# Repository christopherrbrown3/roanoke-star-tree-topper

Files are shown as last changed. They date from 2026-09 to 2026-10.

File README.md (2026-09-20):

# Roanoke Star Tree Topper

<div align="center">






<br>

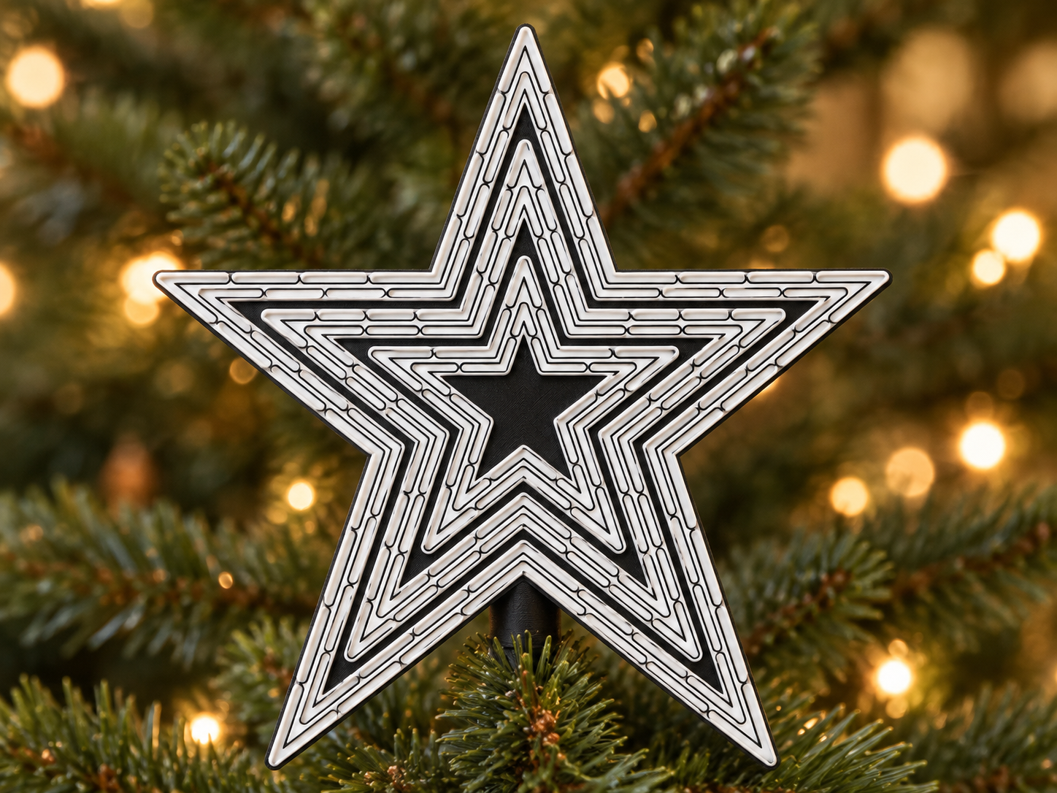
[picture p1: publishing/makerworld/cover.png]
Two-color Roanoke Star tree topper on a lit Christmas tree


<br>

**A research-informed miniature of Roanoke’s Mill Mountain Star**<br>
200 mm · two colors · one print · no assembly

</div>

The Roanoke Star is one of Virginia’s most recognizable night-time landmarks. This tree topper translates its layered neon silhouette into a carefully documented, print-in-place object: a dark structural star, three white backing bands, 130 individually outlined tube sections, and an integrated rear mount for a Christmas-tree leader.

> **Cover note:** The cover is an AI-generated product illustration based on the finished model and owner-supplied print photographs. The project renders and physical-print evidence below are the model’s actual release assets.

## A Christmas landmark since 1949

The Star’s Christmas connection is original to its story. The Roanoke Merchants Association commissioned it for the **1949 Christmas season**, and it was first illuminated on **November 23, 1949**. What began as a seasonal attraction became a permanent symbol above the city. The City of Roanoke records the Star’s height as **88.5 feet**. [City of Roanoke history](https://www.roanokeva.gov/1329/Roanoke-Star)

Roy C. Kinsey Sign Company built the sign with Roanoke Iron & Bridge Works providing the steel structure. Historical accounts credit Robert Little with the design. The full-scale Star was assembled flat on the ground at Roanoke’s airport, taken apart, transported up Mill Mountain, and erected on its tower. [1982 historical account, pp. 88–90](https://www.virginiaroom.org/digital/files/original/67/6354/JHSWV_11_02_1982.pdf) · [WDBJ interview preserved by Virginia Tech](https://scholar.lib.vt.edu/VA-news/WDBJ-7/script_archives/99/1199/112899/112899.m.htm)

The landmark is not a single outline. It is **three nested structural stars** carrying multiple neon sets. Historical descriptions give the Star an 88.5-foot height, a 100-foot supporting tower, a 6.5-foot-deep concrete base, and roughly 2,000 feet of neon tubing. The City’s public-art record and site descriptions confirm the three-star construction. [City description](https://www.roanokeva.gov/1329/Roanoke-Star) · [City art catalog](https://www.artworkarchive.com/profile/roanoke-arts/artwork/roanoke-star)

That layered construction is the heart of this design. The three white bands are the topper’s visual translation of the landmark’s nested neon faces; the dark gaps and rounded tube ends make each run read as an individual piece of neon instead of a single printed line.

## The design in one glance

| | |
|---|---|
| **Scale** | 200 mm tall · 190.96 mm wide · 50.84 mm deep |
| **Face** | Three white star bands with 130 individually outlined tube sections |
| **Construction** | Print-in-place body, face details, and integrated tree socket |
| **Material** | Two compatible PLA colors; dark structural body with white tubes and backing |
| **Target machine** | Bambu Lab A1 with AMS lite · 0.4 mm nozzle · 0.20 mm layers |
| **Assembly** | None; the star and rear mount print as one object |

## From photographs to a printable star

The geometry was developed from municipal records, historical accounts, archival finding aids, aerial views, night photographs, close-up tube studies, and more than fifteen reference views. The research deliberately separates what a photograph can show from what it cannot: an observation-deck photograph looking upward compresses vertical spacing, while an oblique view makes one side appear wider than the other. Those perspective effects are documented in the [perspective audit](research/ACCURACY_AUDIT.md).

The documented 88.5-foot height anchors the scale. Published widths disagree: the Smithsonian inventory records approximately **88.5 × 84.5 feet**, while the City’s art catalog lists **1062 × 1200 inches** without a dimensioned elevation that identifies the axes. This model uses the 84.5/88.5 proportion as its photographic reconstruction basis. Compare the [Smithsonian inventory](https://siris-artinventories.si.edu/ipac20/ipac.jsp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) with the [City art catalog](https://www.artworkarchive.com/profile/roanoke-arts/artwork/roanoke-star); the exact construction is inspectable in the [angle worksheet](research/ANGLE_WORKSHEET.md), [coordinate table](research/candidate_angles.csv), and [parallel-path correction notes](research/PARALLEL_PATH_CORRECTION.md).

The model does not claim to recover an unpublished engineering drawing or the landmark’s complete electrical tube schedule. It is a photo-informed interpretation with explicit dimensions, repeatable construction scripts, and a clear record of the sources and assumptions. The original-plan search examined the Virginia DHR National Register nomination, NPS asset records, the City’s public Engineering plan repository, Virginia Room finding aids, and restoration-report references; no original dimensioned Star elevation or shop drawing was located in the material reviewed. See the [archive search record](research/PLAN_SEARCH.md).

### The tube language

Each nested outline uses a constant inward offset, so corresponding runs remain parallel through every point and recess, including the two lower side interior angles. The [spacing review](research/SPACING_REVIEW.md) compares those offsets with the primary aerial reference. Rounded ends and deliberate dark breaks suggest separate neon lengths, while continuous bends carry the pattern around the star’s corners. A 0.6 mm dark outline keeps the white tube sections legible at FDM scale.

The three broad white backing bands leave approximately **1.6 mm of dark space** between star groups. The tubes and bands are flush inlays, 1.0 mm deep, rather than fragile raised details. White model details occupy the first five layers against the build plate; the dark body, outline, and integrated socket continue above them.

Close photographs show interruptions along straight runs and illuminated bends around corners. A high-resolution Commons photograph provided observations of breaks near the quarter points of one long run; Ben Schumin’s close-up series supplied additional night views. Those observations informed the rounded sections and dark gaps, while symmetry and repetition complete the printable pattern. The **130-section count describes this print**, rather than an inventory of the landmark’s glass tubes or electrical circuits. See the [tube-layout study](research/TUBE_LAYOUT.md), [recorded image observations](research/tube_joint_observations.json), [Schumin close-up series](https://www.schuminweb.com/photography/roanoke-star-night/), and [Commons photograph](https://commons.wikimedia.org/wiki/File:Mill_Mountain_Star_Neon_Lights.JPG).

<div align="center">
<table>
<tr>
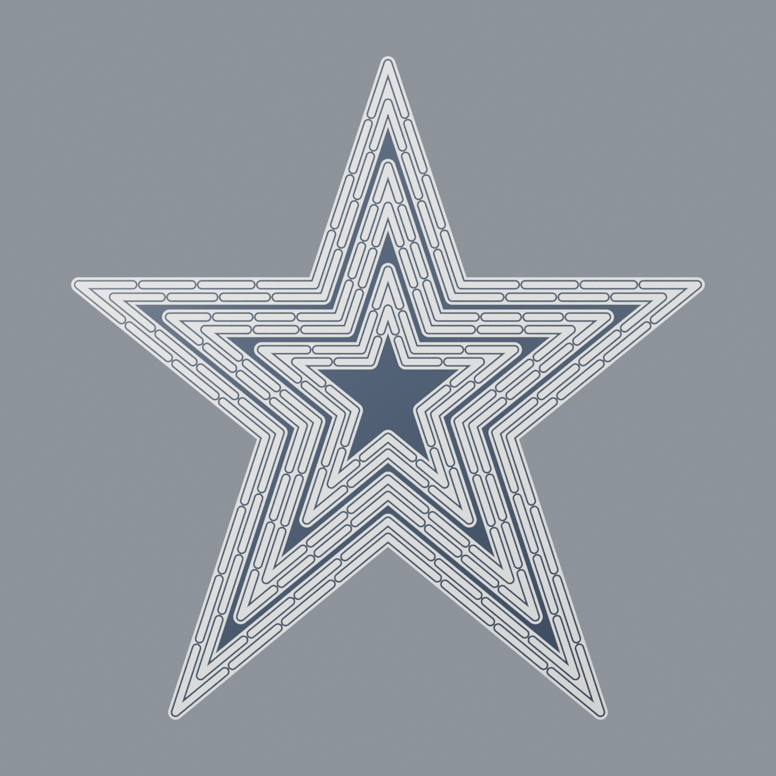
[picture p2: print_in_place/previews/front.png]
Front render showing the three nested white star bands
<td></td>
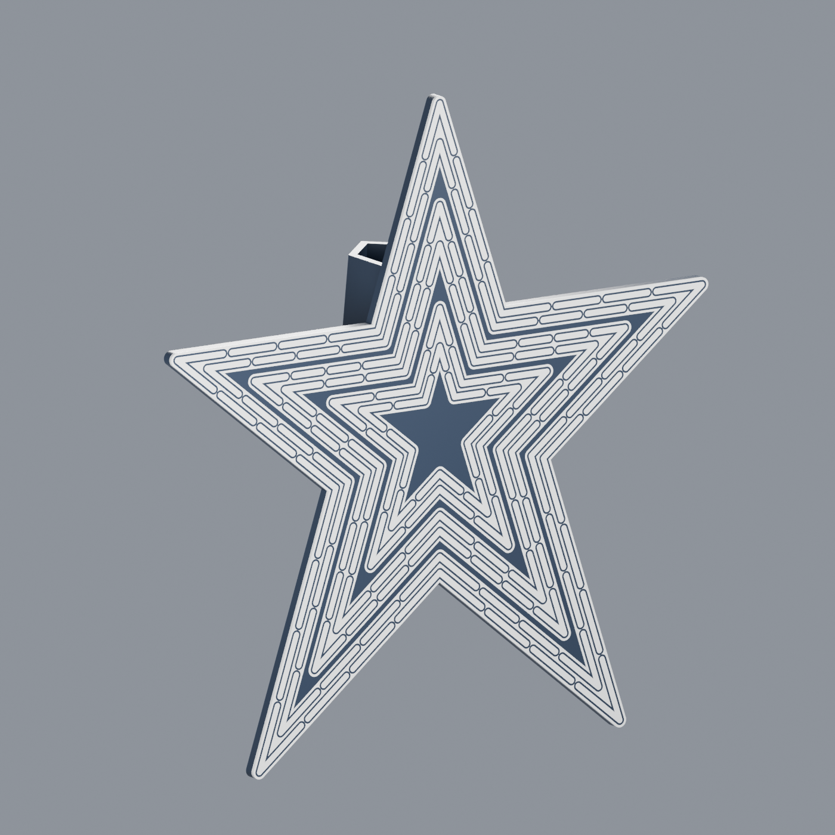
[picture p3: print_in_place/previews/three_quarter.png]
Three-quarter render showing the integrated rear mount
<td></td>
</tr>
<tr>
<td><em>Front: the layered neon pattern</em></td>
<td><em>Three-quarter: one-piece construction</em></td>
</tr>
<tr>
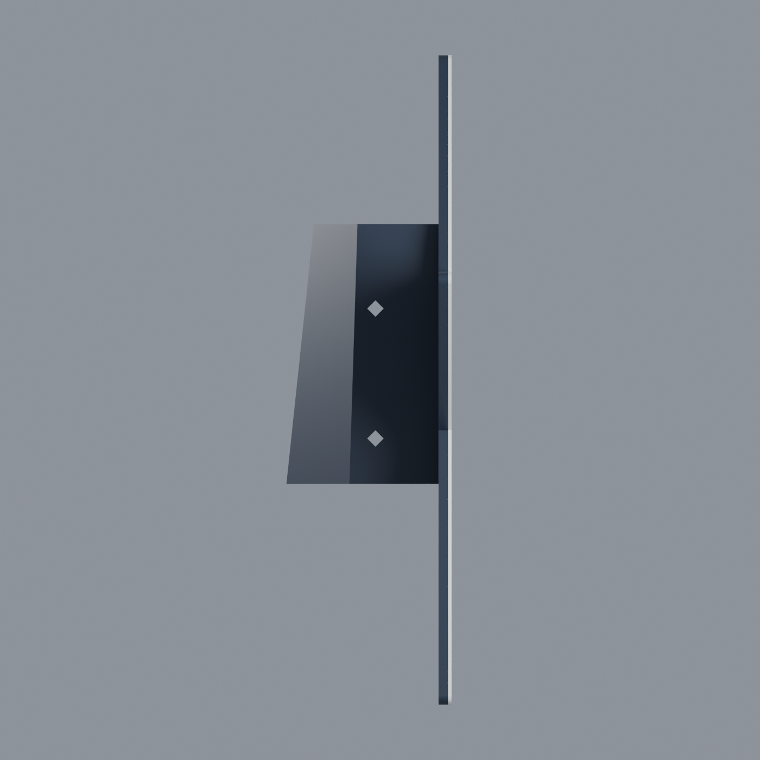
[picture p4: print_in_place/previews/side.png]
Side render showing the topper depth
<td></td>
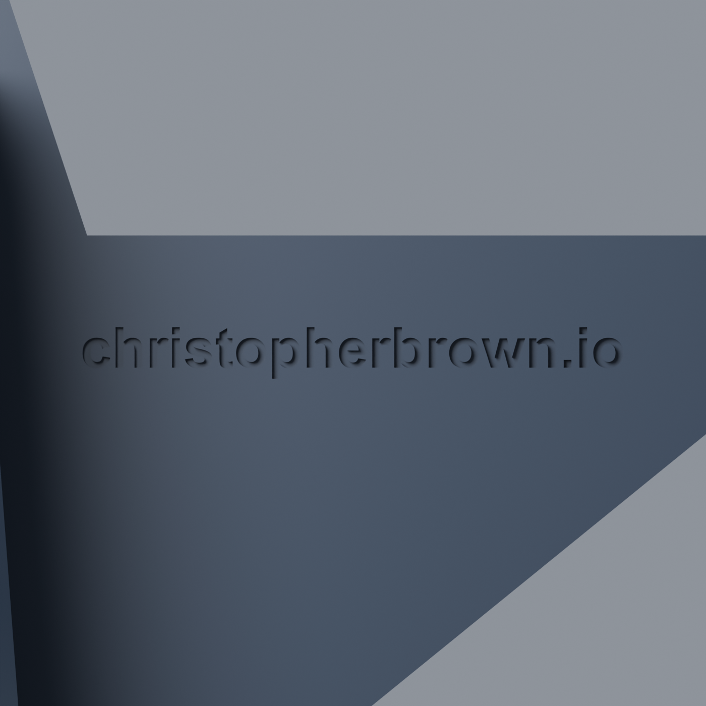
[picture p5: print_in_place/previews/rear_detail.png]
Rear detail render showing recessed christopherbrown.io lettering
<td></td>
</tr>
<tr>
<td><em>Side: shallow face, deep socket</em></td>
<td><em>Rear: recessed attribution</em></td>
</tr>
</table>
</div>

## Download the model

The design is published on MakerWorld with a dedicated A1 profile:

**[Open the MakerWorld model](https://makerworld.com/en/models/3336030-roanoke-star-christmas-tree-topper-2-color)** · **[Open the A1 two-color profile](https://makerworld.com/en/models/3336030-roanoke-star-christmas-tree-topper-2-color#profileId-3789238)**

| File | Use |
|---|---|
| **[Two-color 3MF](print_in_place/roanoke_star_A1.3mf)** | The recommended Bambu Studio project, with two filaments and explicit part assignments. |
| [Editable Blender source](print_in_place/roanoke_star_A1.blend) | Final material meshes, hidden reference paths, and embedded research, license, and validation reports. |
| [Dark body STL](print_in_place/body_material.stl) + [white face STL](print_in_place/white_tube_material.stl) | Alternative material meshes with a shared origin; import together as parts of one object. |
| [Design report](print_in_place/DESIGN_REPORT.md) | Dimensions, mount geometry, material layout, and validation results. |

The finalized [MakerWorld listing copy](publishing/makerworld/LISTING.md) and its [cover illustration](publishing/makerworld/cover.png) are included with the release assets. Personal print photographs used on the listing are intentionally not redistributed here.

## Printing, kept practical

Open the 3MF **as a project** in Bambu Studio. Filament 1 is the dark body and filament 2 is the white face detail; map those project filaments to the appropriate AMS lite spools. Keep the decorated face flat against the build plate and use the included A1 0.4 mm nozzle profile at 0.20 mm layer height.

The project uses four walls, five top and bottom layers, 15% gyroid infill, Arachne walls, and a prime tower, with supports disabled. View layers 1–5 in the slicer to see the two-color face; the full-height view looks mostly dark because the decorated face is against the bed. Select your actual build plate; the included setting is Textured PEI.

The integrated socket is 80 mm long, with nominal circular clearance tapering from **Ø34 to Ø22 mm**. Measure your tree leader before printing. The rear diamond holes accept optional retaining ties when a tree needs extra support.

The validated slice estimates **2 h 47 min and 70.5 g of PLA**, including purge and prime-tower material: 58.6 g dark and 11.9 g white. Your filament profiles and printer settings can change those estimates. The [slicer report](print_in_place/slicer_validation.json) records the exact package checked and the settings read from its exported toolpath.

The owner supplied four photographs of a successful physical print of the revised two-color face. They show the dark body, three white backing bands, and individual white tube sections. The exact slicer profile used for those photographs and post-print mechanical tests were not recorded, so socket fit, strength, and tree retention remain unverified. See the [release status](print_in_place/RELEASE_STATUS.json) for the scope of that evidence.

## Geometry and release validation

The release is checked as a model package, not only as a render:

- Watertight material meshes with consistent winding and no duplicate or zero-area triangles.
- One connected dark body and 133 white solids—130 tube sections and three backing bands—that together form a single connected print.
- Zero non-adjacent triangle-intersection candidates in either material mesh.
- Material coverage matching the complete outer solid within export precision.
- Clearance for the nominal tapered socket mandrel and geometry within the chosen 45° overhang limit.
- Recessed lettering verified for floor, depth, and clearance from the socket.
- A standard 3MF geometry round trip, two filament definitions, and explicit part-to-filament assignments.
- Native Bambu slicing with both colors, preserved process settings, and white extrusion confined to Z = 0.2–1.0 mm.
- Byte-for-byte agreement between the Blender material meshes’ STL exports and the downloadable material STLs.

See the [mesh report](print_in_place/mesh_validation.json), [intersection results](print_in_place/self_intersections.json), [scene/export check](print_in_place/scene_export_validation.json), and [rebuild guide](scripts/REBUILD.md).

## Explore the repository

| Directory | Contents |
|---|---|
| [`print_in_place/`](print_in_place/) | A1 model, material meshes, Blender scene, previews, and validation reports |
| [`scripts/`](scripts/) | Reproducible geometry construction, packaging, and checks |
| [`research/`](research/) | Sources, photograph analysis, angle measurements, and archival research |
| [`publishing/makerworld/`](publishing/makerworld/) | Published listing copy and cover-art provenance |

`main` contains the integrated single-print design shown above. Superseded models and development drafts remain available in Git history.

## Credits and license

Project by [christopherrbrown3](https://github.com/christopherrbrown3). Historical and visual references include the City of Roanoke, Virginia DHR, Roanoke Public Libraries’ Virginia Room, the Smithsonian inventory, Virginia Tech’s WDBJ archive, Ben Schumin, and Wikimedia Commons contributors. See the [source credits](research/SOURCES.md), [photograph inventory](research/GEOMETRY_REVIEW.md), and [supplied-reference provenance](research/user_provided/PROVENANCE.json).

The original model design, geometry data, and downloadable Blender, STL, and 3MF files are licensed under **[Creative Commons Attribution–NonCommercial–ShareAlike 4.0 International](https://creativecommons.org/licenses/by-nc-sa/4.0/)**. You may share and adapt the model for noncommercial purposes with attribution; adaptations must use the same license. See [LICENSE](LICENSE) for the complete terms.

Suggested attribution: **Roanoke Star Tree Topper by [christopherrbrown3](https://github.com/christopherrbrown3) · [christopherbrown.io](https://christopherbrown.io) · CC BY-NC-SA 4.0**. Identify changes when sharing an adaptation.

This license does not relicense third-party reference materials or the historical landmark itself. The back of the model carries recessed `christopherbrown.io` lettering.

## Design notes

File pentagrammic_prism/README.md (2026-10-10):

**Roanoke Star — hollow pentagrammic prism variant**

This is a separate, one-piece tree topper based on the existing A1 model. The original release files are preserved. The front outline, three white backing bands, dark outlines, and all 130 tube positions come from the existing construction profiles. The tube sections are now open slots leading into a hollow star-shaped prism. The old attachment socket is omitted.

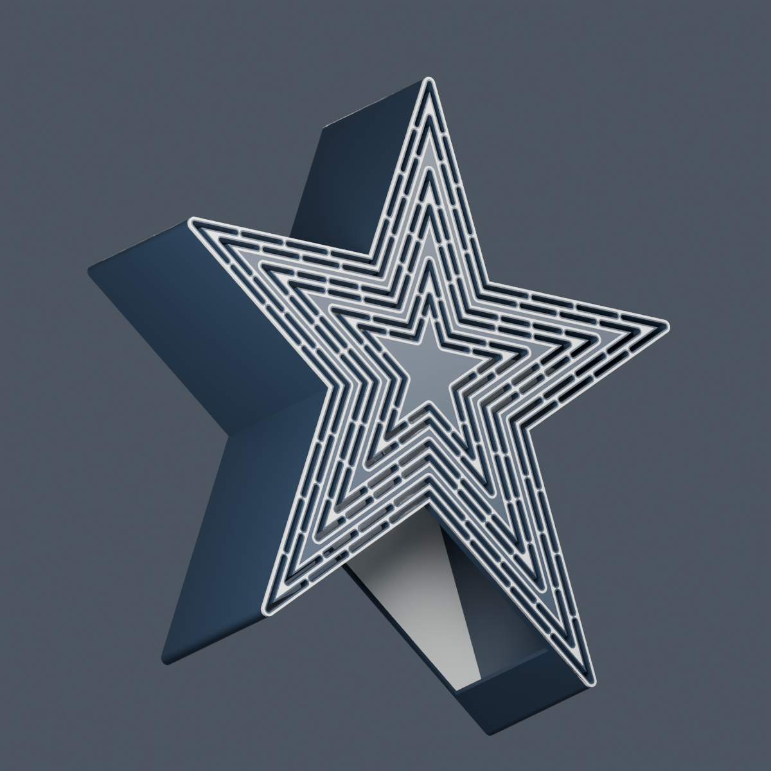
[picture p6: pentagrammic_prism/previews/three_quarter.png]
Hollow prism and lower opening


| Feature | Dimension |
|---|---:|
| Upright height × width × depth | 200 × 190.96 × 60 mm |
| Front wall | 4.0 mm |
| Side wall | 1.2 mm |
| Rear wall | 1.6 mm |
| Open tube slots | 130, nominally 1.8 mm wide |
| Lower inlet width × front-to-back clearance | 100 × 54.4 mm |
| Clear width at the star's waist | About 78 mm |
| Rear vents | Eight diamond openings, 192 mm² total |
| Solid PLA estimate, before brim, support, and purge | 126 g |

The inlet follows the lower V between the two bottom points. Its 100 mm width is intended to admit a gathered bundle of compressible branches and lights. It is not a circular 100 mm bore: the star narrows inside. A tapered 100 mm long tree-leader reference, 33.9 mm wide at its base and 13.9 mm at its tip, clears the model in the digital collision check.

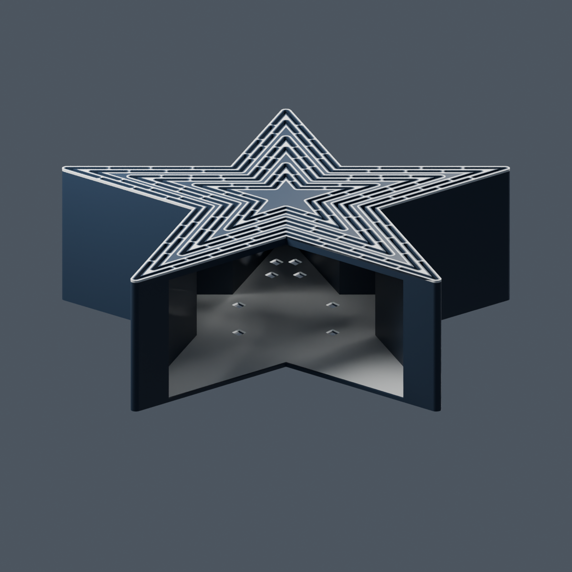
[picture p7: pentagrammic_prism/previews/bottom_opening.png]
View into the lower opening


A white inner rear surface reflects light toward the slots. The separate white mesh is a filament region in the same fused print; there is no removable back, inserted diffuser, or assembly operation. Arrange the tree's existing light string through the lower opening before seating the topper. Actual brightness and coverage depend on bulb positions and foliage.

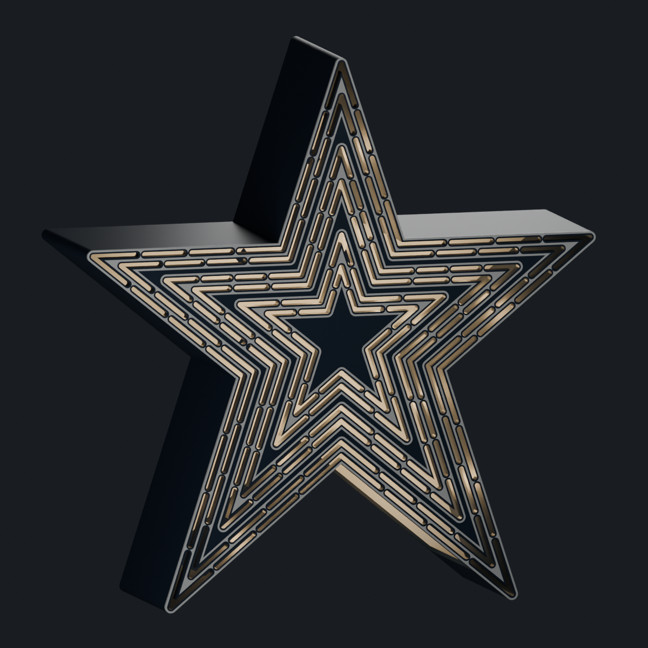
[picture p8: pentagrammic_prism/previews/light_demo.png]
Illustrative internal lighting


The lighting preview is a Blender simulation with illustrative internal lights. It is not a measurement of a real light string. Start physical evaluation with LED or fairy lights. LEDs generally produce less heat than older lighting technologies ([Australian Government lighting guidance](https://www.energy.gov.au/households/household-guides/seasonal-advice/summer?page=7)). Incandescent compatibility has **not** been heat-tested; bulb clearance and ventilation do not establish it. Tree retention, long-term strength, and real illumination uniformity also remain untested.

**Files**

- `roanoke_star_prism.blend`: editable Blender scene, built through Blender MCP. Print geometry is separated from the studio, hidden exterior reference, and optional illumination demonstration.
- `roanoke_star_prism_A1.3mf`: one multipart object with navy shell on filament 1 and white face bands/interior reflector on filament 2. Intended for the A1 and AMS lite, with a 45° print tilt, 0.4 mm nozzle, and 0.20 mm layers.
- `roanoke_star_prism_A1_single_color.3mf`: same fused geometry in one white filament, with no prime tower. Geometry and package round trip checked; its GUI slice remains pending.
- `roanoke_star_prism.stl`: complete single-piece geometry for a monochrome print. White bands lose their color distinction when printed this way.
- `dark_shell.stl` and `white_details.stl`: alternative two-material imports. Import together as parts of one object and preserve their shared origin.
- `previews/`: front, rear, three-quarter, lower-opening, and illustrative lighting views.
- `parameters.json`, `profiles.json`, and the Python sources: inspectable dimensions, geometry preparation, Blender construction, and independent validation/packaging.
- `mesh_validation.json`, `canonicalization_report.json`, and `blender_validation.json`: digital geometry evidence.

The tilted model occupies approximately 191 × 184 × 184 mm. The tilt keeps the planar faces and extruded walls within a 45° surface-overhang envelope, avoiding a large horizontal interior roof. A wide adhesion brim is included for the two lower tips, and automatic tree support is enabled from the build plate. Review the slice before printing. The slanted two-color face requires color changes through many layers and can consume substantially more purge material than the original face-down design.

The completed two-color slice in Bambu Studio 02.05.00.66 estimates **42 h 32 min and 661.49 g**, including 459.97 g of purge and 66.99 g for the tower, with 910 filament changes. The model itself is 118.95 g in the slicer estimate. No print was sent. The G-code hash, package hash, settings, and review scope are saved in `slicer_validation.json`; generated G-code stays local and is ignored by Git.

**Rebuilding**

Run `python3 pentagrammic_prism/prepare_profiles.py` from the repository root. This creates the simple source extrusions in `construction/` without modifying the original profiles or release. The preparation script requires NumPy, Trimesh, Shapely, and mapbox-earcut.

In a fresh Blender scene connected through MCP, send the contents of `build_blender.py` to `execute_blender_code`, followed by `setup()` and `build_shell()`. For the next call, resend the function definitions, call `restore()`, then `partition_colors()` and `finish()`. The code uses native imports, booleans, rendering, and saving compatible with MCP safe mode. It does not need Python file access within Blender. If changing dimensions, update the preparation configuration and pass the corresponding parameter dictionary as `C` before the build calls.

Run `canonicalize_exports.py` locally after the native exports. Return the canonical meshes to their matching Blender objects using native STL import, preserving the materials and scene properties; re-export the material meshes. Run Blender's BVH check with zero extra tolerance. The supplied final meshes have zero nonadjacent intersection candidates. Then run `python3 pentagrammic_prism/validate_and_package.py` to check the files and rebuild the 3MF. The validation script also requires Manifold3D.

The independent checks verify watertight material meshes, a single connected fused shell, preserved face footprints, 130 matching apertures, cavity and mouth clearance, material coverage, a collision-free leader reference, and 3MF round-trip geometry. They do not substitute for a physical print or thermal test. Slicer evidence, when present, is recorded separately in `slicer_validation.json`.

Original model and this adaptation: christopherrbrown3 / christopherbrown.io, **CC BY-NC-SA 4.0**. See the repository's `LICENSE`, also embedded in the 3MF.

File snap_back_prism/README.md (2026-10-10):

**Roanoke Star — snap-back prism experiment**

This is a separate two-piece experiment based on the one-piece prism checkpoint, commit `fcb757d`. The original release and the committed prism files are preserved. It retains the original 200 mm face, three white bands, and 130 light apertures. The star is 60 mm deep with the same 100 × 54.4 mm lower opening; the cavity narrows to about 78 mm at its waist.

**Use the [full two-dot revision](two_dot/README.md) for the next topper print.** Both larger connector trials worked in the user's physical test, with a slight preference for two dots. The new revision uses that connector at all six positions, with matching larger catch windows. Print its matching front and back together; the files directly in this directory retain the earlier latch for comparison.

The preferred cover also carries a larger inset **christopherbrown.io** builder mark on its outside, 72 mm wide and 1 mm deep.

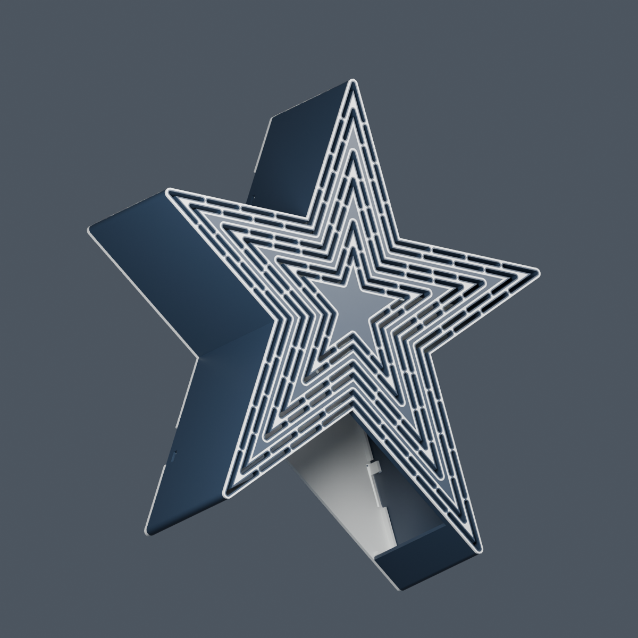
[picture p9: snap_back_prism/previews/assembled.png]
Assembled snap-back prism


The front shell prints face down with its rear open. A separate white rear cover provides the light-reflecting surface and snaps into six small windows in the side walls. A 3 mm locating rim guides it into place. Both parts slice without supports; the body has a 4 mm adhesion brim.

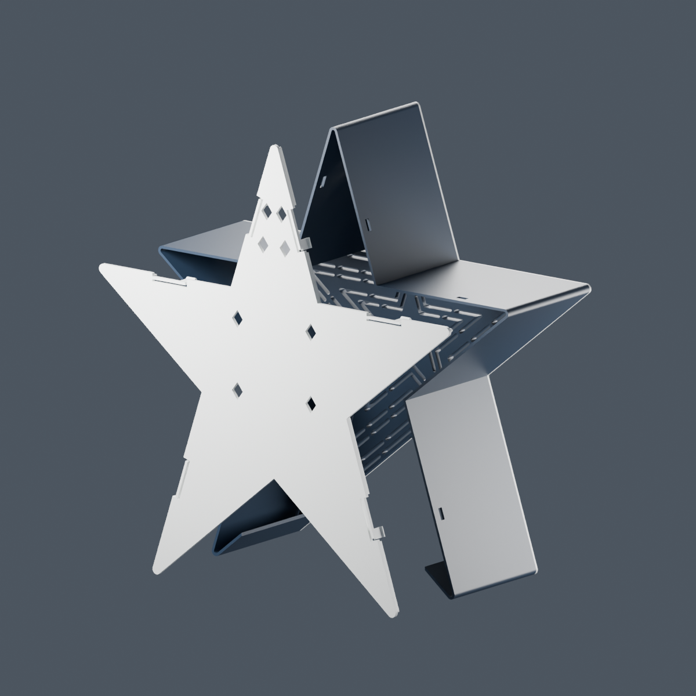
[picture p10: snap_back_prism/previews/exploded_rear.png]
Detached rear cover


Actual Bambu Studio 02.05.00.66 estimates for the A1, 0.4 mm nozzle, Generic PLA, and 0.20 mm layers:

| Print | Estimated time | Filament |
|---|---:|---:|
| Committed one-piece, two-color prism | 42 h 32 min | 661.49 g |
| Face-down front shell | 3 h 39 min | 92.72 g |
| Separate white back | 57 min | 29.09 g |
| **Snap-back topper total** | **4 h 36 min** | **121.81 g** |
| Connector sample, separate optional print | 16 min | 1.43 g |

The topper uses about **82% less filament and 89% less estimated time** than the one-piece two-color slice. The front consumes 2.35 g of purge and 0.49 g of tower material. Its six tool selections include the initial load and five color switches, all within the first 1 mm of printing. The back uses white filament only. Times include each plate's startup estimate.

**Try the small snap sample first**

The original [connector_sample_A1.3mf](connector_sample_A1.3mf) reproduces the same wall, window, spring, ramp, and locating rim as the full model. The intended behavior is that the cap seats flat with its nose in the window, stays attached, and releases without cracking. This baseline has 0.30 mm radial running clearance and 0.45 mm catch engagement. Holding force has not been measured.

The first physical sample was printed on October 3, 2026. The user reported that it stopped short of seating or required too much force, and that the small bases were difficult to remove from the plate. The [larger connector trials](connector_fit_v2/README.md) use longer spring arms, broader hooks, more guide clearance, and beveled grip edges. Both worked; the user slightly preferred the two-dot pair. The actual trial print used AMS A1's Generic PLA Silk profile, with an estimate of 32 min 49 sec and 8.85 g total. The [full two-dot revision](two_dot/README.md) applies the preferred profile to the topper. [Research and mechanism comparison](connector_fit_v2/research.md).

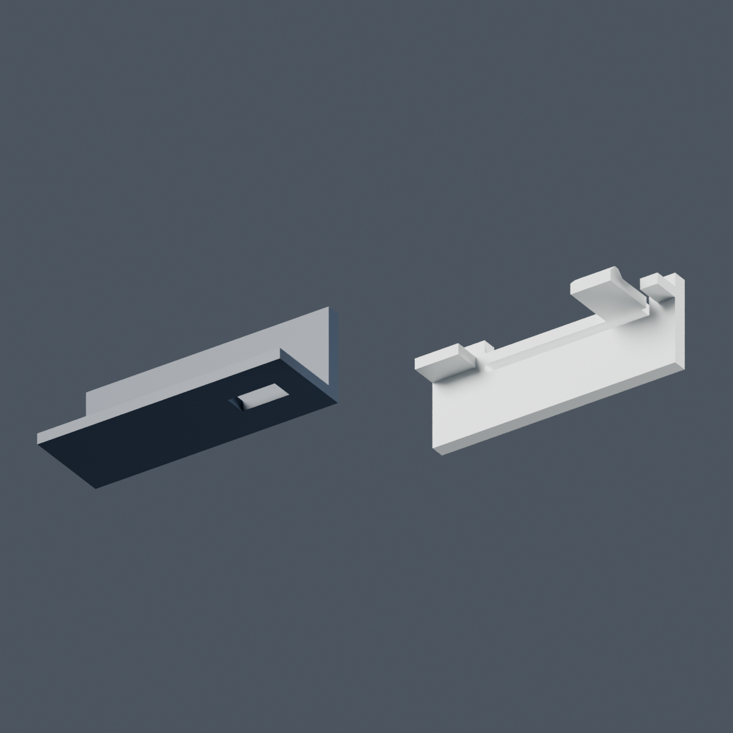
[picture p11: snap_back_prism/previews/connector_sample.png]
Connector sample


The clip's flexible arm is approximately 18 mm long and 1.2 mm wide in the plane of the back plate. Its hook projects toward the shell and uses 45° ramps. The layout follows the recommendation to orient FDM snap flexures within XY ([Formlabs snap-fit guide](https://formlabs.com/blog/designing-3d-printed-snap-fit-enclosures/)). A simple cantilever estimate gives roughly 0.42% strain for the nominal 0.75 mm insertion deflection. This estimate does not establish a fatigue life or safe holding force for a particular filament. If the sample needs adjustment, tune `radial_fit_gap_mm` or `retention_engagement_mm` in the preparation source and regenerate the actual matching profiles.

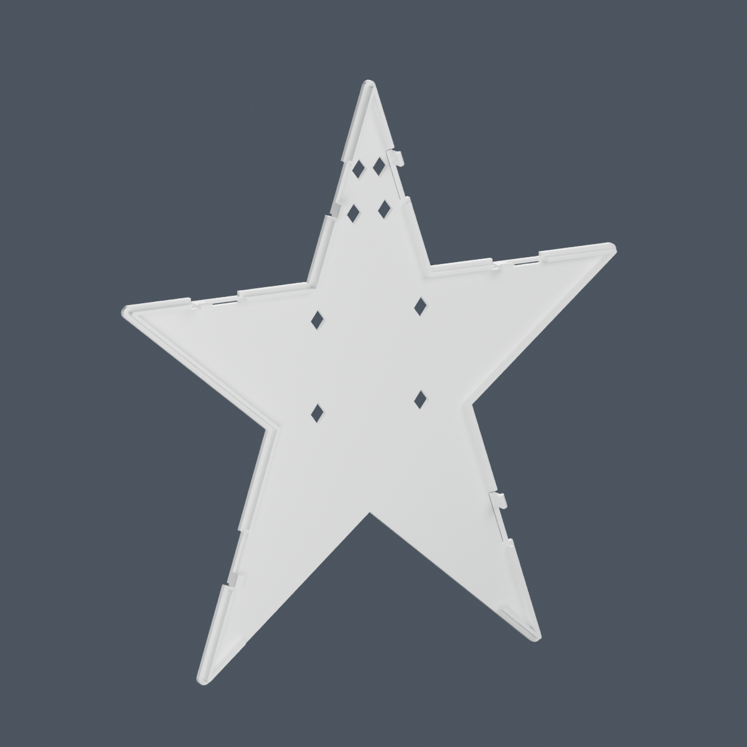
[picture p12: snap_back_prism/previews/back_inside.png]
Locating rim and six clips


**Print and design files**

- [front_shell_A1.3mf](front_shell_A1.3mf): face-down shell; navy on filament 1, original white face bands on filament 2. Preserve the supplied multipart alignment.
- [snap_back_A1.3mf](snap_back_A1.3mf): outer face down, rim and hooks up; white on filament 2. The project retains the same two-filament A1 configuration, but this plate prints only white.
- [snap_back_prism.blend](snap_back_prism.blend): editable assembled scene built through Blender MCP, with separate shell, cover, connector sample, and studio collections.
- `body_navy.stl`, `body_white_face.stl`, `snap_back.stl`: matching assembly coordinates. The shell's two material meshes form one connected print. `front_shell_fused.stl` is its single-color alternative.
- `coupon_catch.stl`, `coupon_back.stl`: sample in matching assembly coordinates; the 3MF already arranges them in their print orientations.
- `parameters.json`, `mesh_validation.json`, `blender_validation.json`, and `slicer_validation.json`: dimensions and digital verification evidence. Generated G-code is kept locally under `slicer_check/` and ignored by Git.

The geometry checks passed: watertight material meshes, one connected shell, one connected back, no seated assembly collisions, matching front footprints and 130 apertures, clear bottom opening and tree-leader reference, real catch undercuts, and 3MF round trips. Blender's BVH checks found zero nonadjacent intersection candidates. A geometric sweep also clears the hook heads after the nominal inward displacement; it does not model actual spring bending or assembly forces.

This remains an experiment pending a real snap-fit and tree-fit test. Heat and illumination have not been measured, and incandescent compatibility is unverified. Use LED or fairy lights for initial evaluation.

**Rebuilding**

Run `python3 snap_back_prism/prepare.py` from the repository root. Send `build_blender.py` through Blender MCP in a file that has the existing navy/white material definitions and no prior snap-back scene: call `setup()` and `build_body()`, then resend the definitions, call `restore()`, `build_back()`, and `finish()`. When changing the fit, supply the corresponding parameter dictionary as `C` after the definitions in each call. The code creates a new scene and saves only in this experiment's directory.

Run `python3 snap_back_prism/canonicalize.py` locally, then send the Blender definitions again and call `restore()` and `import_canonical()` to synchronize the cleaned export meshes into the scene. Run `python3 snap_back_prism/validate_and_package.py` for clearance checks and native A1 package creation. The local scripts require NumPy, Trimesh, Shapely, mapbox-earcut, and Manifold3D. Re-slice changed packages in Bambu Studio and export their G-code as `slicer_check/front.gcode`, `back.gcode`, and `sample.gcode`; `audit_slices.py` records the matching hashes and comparison.

Original model and adaptation: christopherrbrown3 / christopherbrown.io, **CC BY-NC-SA 4.0**. See the repository's `LICENSE`, also included in each 3MF.

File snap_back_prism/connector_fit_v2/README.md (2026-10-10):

The original connector print stopped short of seating or required excessive force, according to the user's physical test. These two small revised samples address insertion before changing the full topper.

**Physical result:** the user reported, “They both work. Slight edge to two dots though.” The **two-dot, 0.50 mm engagement** connector is the selected profile for the [full topper revision](../two_dot/README.md). The result applies to individual connector pairs printed using A1's Generic PLA Silk profile. See [physical_fit.json](physical_fit.json).

Both use a larger cantilever latch: a 30 mm arm with a 1.6 mm width in the bending direction and an 8 mm broad hook. The original used an approximately 18 mm arm, 1.2 mm width, and 4.6 mm hook. The new guide clearance is 0.55 mm (original: 0.30 mm), with 2 mm of relief beside the arm, a 1.6 mm entry ramp, and a wider catch window. The one-dot pair has 0.30 mm catch engagement; the two-dot pair has 0.50 mm. The original had 0.45 mm engagement.

The test bases are now 48 × 20 mm, compared with 28 × 10 mm, with rounded corners, a thickened grip at the far edge, and a 1 mm bevel underneath that edge. The bevel provides a starting point for lifting after the plate cools and is flexed. These handling features are outside the mating surfaces.

Match the dots on each wall and cap. Try one dot first, then two dots. Turn the cap over so the hook points down, align the hook with the window, and press the cap over the wall. Report whether it seats fully, holds after release, and survives removal. For comparable retries, use the same filament as the test being compared.

The matching A1 project is `connector_fit_v2_A1.3mf`, with a 0.4 mm nozzle and 0.20 mm layers, without supports or a prime tower. Digital checks do not establish physical fit or holding force. The original connector, full topper, and original release files are preserved.

Bambu Studio 02.05.00.66 initially sliced the saved project successfully: **29 min 15 sec and 8.85 g of white PLA**, including startup. There are 50 layers, with a maximum height of 10 mm. See `slicer_validation.json` for the package hash and observed results.

On October 3, 2026, the user requested printing with **AMS slot A1**. Its synced profile was **Generic PLA Silk, magenta**. All four parts were assigned to that profile and re-sliced in Bambu Studio: **32 min 49 sec and 8.85 g**. The send dialog confirmed A1, and the printer accepted the job and began heatbed preheating. Bed leveling and flow dynamics calibration were enabled; timelapse was off. The saved 3MF was not overwritten with these runtime filament changes. This test uses a different filament from the original white sample, so material may also affect the physical fit result.

The research and choice of mechanism are recorded in [research.md](research.md). These are new trial dimensions, not a copy of a downloaded model or a physically proven topper latch.

Rebuild with `python3 snap_back_prism/connector_fit_v2/prepare.py`, then execute `build_blender.py` definitions through Blender MCP and call `setup()`, `build_trial('one_dot', 1, -15)`, `build_trial('two_dot', 2, 15)`, and `finish()`. Run `validate_and_package.py` locally and slice the resulting project in Bambu Studio.

Original model and adaptation: christopherrbrown3 / christopherbrown.io, CC BY-NC-SA 4.0. See the repository's `LICENSE`.

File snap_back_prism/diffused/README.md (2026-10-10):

This variant has **three continuous white star bands**, with no black outlines around the bulbs. All **130 original bulb shapes** remain as hidden light windows behind a **0.4 mm white skin**, flush with the front face. The surrounding white is 1 mm thick, with black backing from Z = 1 mm behind it to keep the illuminated pattern distinct. At the supplied 0.20 mm layer height, each bulb window has two printed layers.

The face prints down against the plate. The white bands and thin windows now form three connected white solids instead of 133 separate pieces. The combined shell geometry, bulb positions, and outside dimensions match the preceding diffused version; this revision transfers the visible black bulb outlines to white.

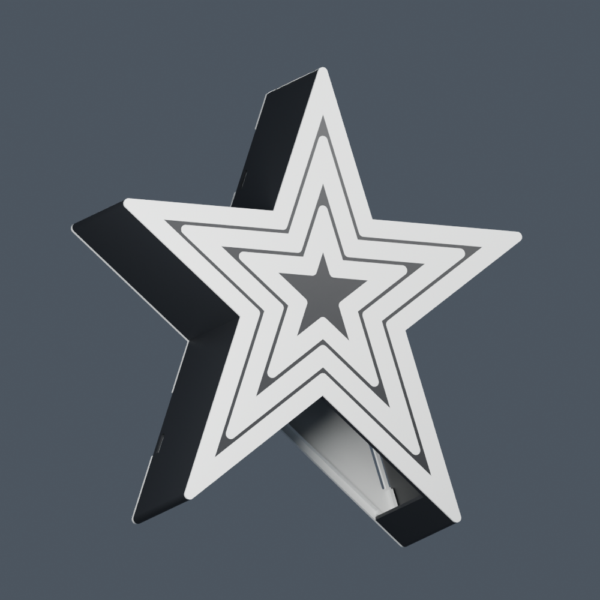
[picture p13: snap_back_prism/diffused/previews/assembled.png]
Unlit diffused star face


The 200 mm outline, 60 mm depth, 100 mm bottom entrance, and preferred two-dot connector are retained. Use the marked back from [../two_dot/snap_back_A1.3mf](../two_dot/snap_back_A1.3mf). Its inset `christopherbrown.io` mark remains 72 mm wide and 1 mm deep. The original release and earlier open-window designs are preserved.

- [diffused_front_A1.3mf](diffused_front_A1.3mf): full front shell, white on project filament 1 / AMS A1 and black on project filament 2 / AMS A2.
- [diffuser_test_A1.3mf](diffuser_test_A1.3mf): 64 × 44 × 4 mm sample at actual scale, with six complete windows and further cropped windows from the real face. A 2 mm black handling border joins the sample and provides larger edges for removal.
- [diffused_topper.blend](diffused_topper.blend): editable Blender scene containing the full topper and the test sample.
- [parameters.json](parameters.json), [mesh_validation.json](mesh_validation.json), [slicer_validation.json](slicer_validation.json), and [slice_comparison.json](slice_comparison.json): dimensions, independent geometry checks, actual test toolpaths, and native slice estimates.

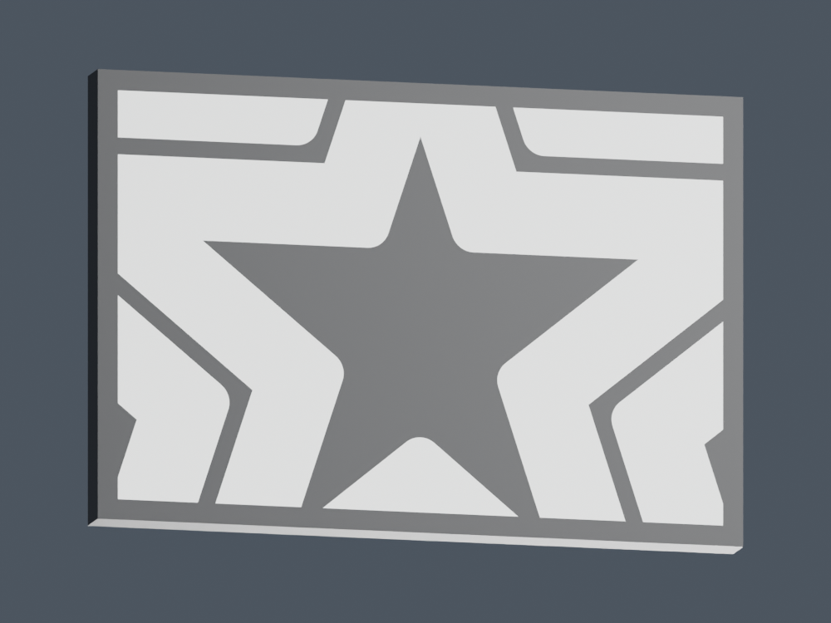
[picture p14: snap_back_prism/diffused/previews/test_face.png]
Actual-size test face


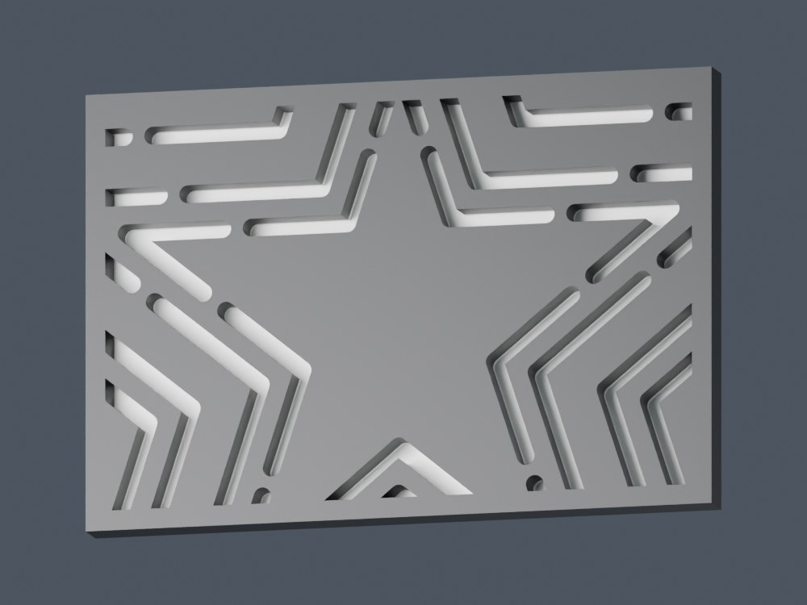
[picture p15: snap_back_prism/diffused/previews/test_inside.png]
Inside of the sample showing recessed thin windows


Bambu Studio 02.05.00.66 sliced both the full front and sample for the A1 with a 0.4 mm nozzle, Generic PLA, 0.20 mm layers, no supports or brim, and a prime tower. Exported G-code uses Textured PEI at 65 °C. Estimates include startup, purging, and the slicer's timelapse allowance:

| Project | Estimated time | Filament |
| --- | ---: | ---: |
| Previous outlined diffused front, commit `8bfcef2` | 3 h 50 min 58 sec | 95.32 g |
| Continuous white front | 3 h 55 min 24 sec | 95.01 g |
| Continuous white test sample | 51 min 37 sec | 12.90 g |

The full front uses 0.31 g less filament and takes an estimated 4 min 26 sec longer under matching settings. Removing the outlines simplifies the white geometry and appearance; the tall shell still accounts for most printing. The test has 20 layers. G-code checks verify white extrusion on layers 1 and 2 only in each of its six intact windows, no black extrusion inside those windows, and no black paths inside the continuous white star faces on the first two layers. Buffered toolpaths cover approximately 97.7% and 98.1% of the star-band interiors; this is a path-width approximation, not a measurement of the printed surface.

The **preceding outlined sample** was sent on 2026-10-04 to printer **3DP-039-922** as **Star_diffuser_test_0.4mm**, with white in physical A1 and black in A2. It continues to test the same two-layer white windows. Its print evidence is preserved in [outlined_test_print.json](outlined_test_print.json), [outlined_test_mesh_validation.json](outlined_test_mesh_validation.json), and [outlined_test_artifact_hashes.json](outlined_test_artifact_hashes.json); its model files are recoverable from commit `8bfcef2`. Completion and physical optical results are pending.

The revised sample is prepared separately and has **not been sent while the earlier sample occupies the plate**. The requested physical materials remain **white in A1 and black in A2**. A1's saved registration still reports magenta PLA Silk. A temporary sending copy uses that nominal color to let Bambu select A1, with identical geometry and Generic PLA extrusion settings. Both physical slots were verified in the send dialog, which reports the printer is busy. The revised sample is left sliced in Bambu Studio; [print_preparation.json](print_preparation.json) records that preparation. The canonical projects and previews remain white and black. Verify physical slots before sending and clear the finished print from the plate.

The membranes and complete front form one connected print. Dimensions, material boundaries, exported meshes, native slicing, and Blender triangle intersections have been checked. Actual brightness, diffusion, and unlit appearance require inspecting the physical sample with the intended lights. The assembled full topper and the force of all six clips remain to be tested.

To rebuild, run `python3 snap_back_prism/diffused/prepare.py`. Send `build_blender.py` through Blender MCP and call `setup()`, `build()`, and `finish()`. Run `validate_and_package.py`, then reimport the canonical meshes through Blender MCP with `restore()` and `import_canonical()`. The rear cover is imported directly from the preferred two-dot revision. Render the actual meshes with `preview_blender.py`, `setup_studio()`, `render_diffused()`, and `finish()`.

After slicing the sample, export the plate sliced file in Bambu Studio and run `python3 snap_back_prism/diffused/audit_sliced_test.py /absolute/path/to/sample.gcode.3mf`. This checks the material and layer count from actual extrusion instructions. Re-slice every changed project before printing.

Original model and adaptation: christopherrbrown3 / christopherbrown.io, CC BY-NC-SA 4.0. See the repository's `LICENSE`.

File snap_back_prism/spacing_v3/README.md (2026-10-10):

# Thinner star frames, spacing draft v3

This draft reduces the white band widths and widens the visible black gaps after comparison with the supplied daylight aerial photograph. The three white bands now have similar widths. A narrow black border, approximately 1.2 mm wide along straight edges, surrounds the outside star.

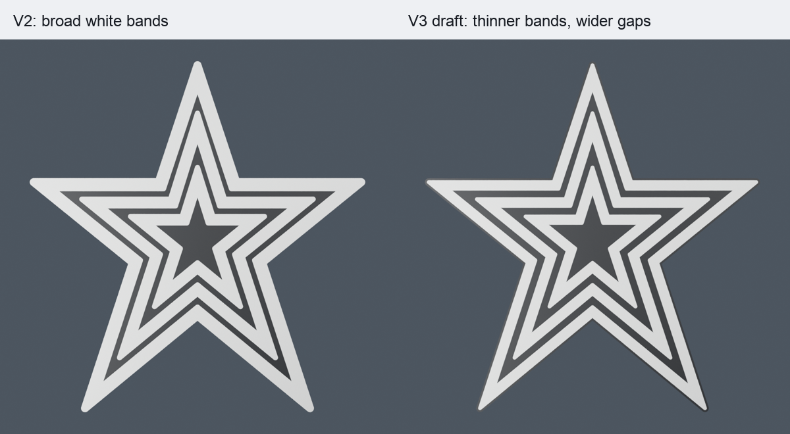
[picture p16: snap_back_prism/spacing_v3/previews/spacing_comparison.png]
V2 and the new spacing draft


| Measurement | V2 | V3 draft |
| --- | ---: | ---: |
| Outer white band at shoulder | 7.34 mm | 5.74 mm |
| Middle white band at shoulder | 6.59 mm | 5.79 mm |
| Inner white band at shoulder | 6.46 mm | 5.66 mm |
| Outer-to-middle clear gap at shoulder | 3.19 mm | 3.99 mm |
| Middle-to-inner clear gap at shoulder | 3.27 mm | 4.07 mm |
| Closest outer-to-middle gap anywhere | 2.06 mm | 2.86 mm |
| Closest middle-to-inner gap anywhere | 2.64 mm | 3.44 mm |

The photograph suggests roughly 9–10 pixels of frame width and 8 pixels of open gap at the measured horizontal shoulder. These are approximate readings from a perspective photograph, recorded in `photographic_band_measurements.json`; they are not surveyed dimensions. The model's gaps vary around the star because the established nested paths are retained. This draft changes the white backing margin around those paths, rather than changing their proportions again.

All six light-track paths and all 130 hidden window polygons are identical to V2. The windows retain their 0.4 mm white diffuser floors, and the unlit face has three continuous white stars without individual black bulb outlines. The fused shell geometry, 100 mm tree entrance, six catches, and marked two-dot back are also retained. The back STL and its print project are byte-identical to the previous back; its inset `christopherbrown.io` mark is 72 mm wide and 1 mm deep.

## Files to use

- `front_shell_A1.3mf`: two-material front shell, positioned face down; project filament 1 is white for A1, and filament 2 is black for A2.
- `roanoke_star_spacing_v3.blend`: editable Blender scene with the new front, matching back, and render lighting.
- `snap_back_A1.3mf`: matching all-white back. The previously printed marked two-dot back remains compatible.
- `body_black.stl` and `body_white_diffused.stl`: separate material meshes in their assembled coordinates.
- `front_shell_fused.stl`: the unchanged single-material geometry reference. Use the front 3MF for the intended colors.
- `previews/front.png`, `previews/assembled.png`, and `previews/spacing_comparison.png`: renders of the exported meshes.

## Verification

The black and white material meshes pass watertightness and positive-volume checks. Live Blender reports zero boundary edges, zero non-manifold edges, and zero nonadjacent triangle intersection candidates for the front materials and back. The seated back has no measured solid collision. Hash comparison confirms that all 160 protected earlier files, including V2, remain unchanged.

Native Bambu Studio slicing uses the A1 with a 0.4 mm nozzle, 0.2 mm layers, a 65 C textured PEI plate, two Generic PLA profiles, a prime tower, and no supports or brim. The front slice has 292 layers and reaches 58.4 mm. Its estimate is 3 hours 50 minutes 46 seconds and approximately 94.83 g, including flushing and the tower.

An independent audit of the first 20 layers checks the three continuous white bands and all 130 window interiors. Each window receives white on exactly layers 1 and 2, with no black extrusion in its audited interior. Buffered toolpaths with rounded bead ends approximate deposited coverage; the audited window cores exceed 90% coverage on each layer, 99% on layer 2, and 99.9% across both layers. This is a toolpath check, not a physical translucency or airtightness test.

See `mesh_validation.json`, `blender_validation.json`, `slicer_validation.json`, and `preservation_validation.json` for the checks and hashes. This spacing revision has been rendered and sliced; it has not been sent to the printer or physically tested.

## Regeneration

From the repository root, run `python3 snap_back_prism/spacing_v3/build.py`. Dependencies are `numpy`, `trimesh`, `manifold3d`, `shapely`, and `mapbox_earcut`. The script reads the V2 source and geometry snapshot files included in `../proportions_v2/`, plus earlier geometry helpers, and writes only this revision directory. Its default is three thinner white bands with the narrow black outside border. The optional `--keep-white-outer-edge` flag restores the earlier white outside edge while retaining the thinner two inner bands; that alternative requires fresh renders, a native slice, and a new audit.

For Blender MCP, submit the contents of `build_blender.py` as Python code, followed by `setup()`, `validate()`, `studio()`, `render_front()`, `render_assembled()`, and `save()`. If the revision scene already exists, use `restore()` and `reload_meshes()` instead of `setup()`, and reuse the existing studio. The code runs directly in Blender's safe mode without a file-reading or `exec` wrapper.

After exporting the native Bambu slice, run `python3 snap_back_prism/spacing_v3/audit_slices.py /path/to/plate.gcode.3mf`. The slicer report applies only to the front 3MF identified by `source_front_sha256`; rebuilding geometry requires slicing and auditing the current project again.

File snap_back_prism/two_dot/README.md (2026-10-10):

This is the full topper revision using the **two-dot connector** that the user slightly preferred after both test pairs worked. The original release, one-piece prism, earlier snap-back experiment, and printed test pairs are preserved.

The front retains the same 200 mm face, original white bands, and 130 light apertures. The star remains 60 mm deep with the same 100 mm bottom opening. The back has six 30 mm cantilever arms, 1.6 mm bending width, 2 mm relief, 8 mm hooks, 0.55 mm guide clearance, and 0.50 mm engagement. The shell has matching 9.2 mm catch windows. The hook meshes are direct transforms of the tested two-dot hook.

The outside of the rear cover has an inset **christopherbrown.io** builder mark, 72 mm wide, about 6.9 mm tall, and 1.0 mm deep. It is 52% wider and 67% deeper than the original 47.5 mm / 0.6 mm mark. The lettering retains a 0.6 mm floor and clears the vents and clips. Arial Bold is converted to mesh; the font file is not distributed.

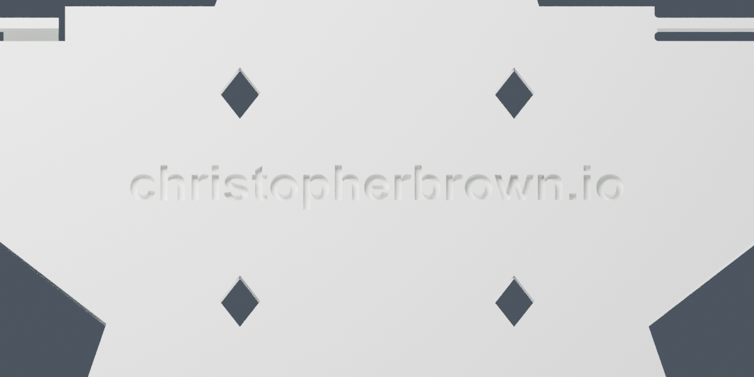
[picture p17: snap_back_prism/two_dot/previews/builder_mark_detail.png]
Recessed builder mark on the outside of the back cover


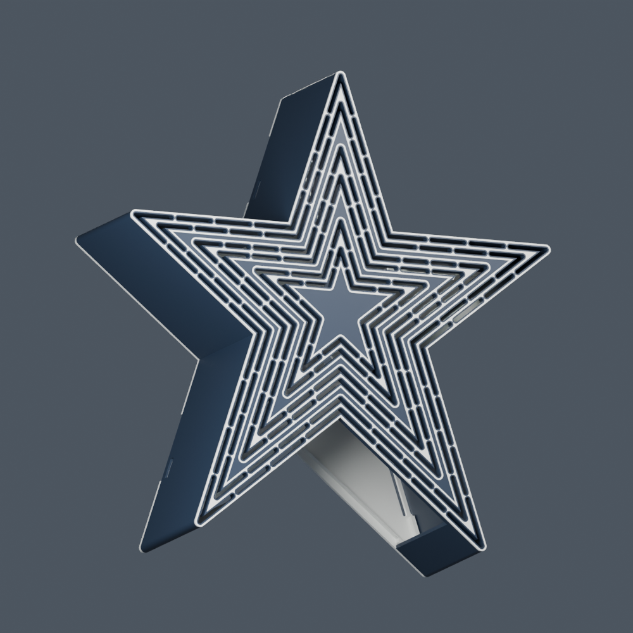
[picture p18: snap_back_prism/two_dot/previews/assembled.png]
Full two-dot topper


Bambu Studio 02.05.00.66 sliced both matching plates for the A1, 0.4 mm nozzle, Generic PLA, and 0.20 mm layers:

| Plate | Estimated time | Filament |
|---|---:|---:|
| Front shell | 3 h 39 min | 92.59 g |
| Detachable back with builder mark | 59 min 42 sec | 28.93 g |
| **Total** | **About 4 h 39 min** | **121.52 g** |

Times include startup for both plates. Neither requires supports. The front has a 4 mm brim and a purge tower for its face colors; the back has neither. The engraving appears through layer 5 at 1.0 mm, and its floor closes at layer 6 at 1.2 mm. The front package is unchanged from its previous verified slice. See [slicer_validation.json](slicer_validation.json) for package hashes and observed results. The new full topper has not been sent to the printer.

- [front_shell_A1.3mf](front_shell_A1.3mf): matching front shell, face down; navy on project filament 1 and original white bands on project filament 2.
- [snap_back_A1.3mf](snap_back_A1.3mf): matching back, outer face down with clips up; white on project filament 2.
- [two_dot_topper.blend](two_dot_topper.blend): separate editable scene built through Blender MCP.
- [parameters.json](parameters.json) and [mesh_validation.json](mesh_validation.json): dimensions, coupon comparisons, mesh integrity, assembly clearance, and package checks.
- [builder_mark_validation.json](builder_mark_validation.json): actual engraved-floor and removed-material comparisons, dimensions, and clearances.

Use both plates from this directory. The wider hooks require these matching shell windows. Map project filaments to the desired physical AMS slots before sending a full print. The successful individual test used slot A1, synced as Generic PLA Silk, magenta; the supplied full topper projects retain the original navy/white color scheme.

The individual connectors worked in the user's physical test. The assembled full topper and combined force of its six latches still need a physical check. Assembly, tree opening, and deflected-hook corridor checks are geometric checks; they do not predict force. Thermal and incandescent-light compatibility remain unverified.

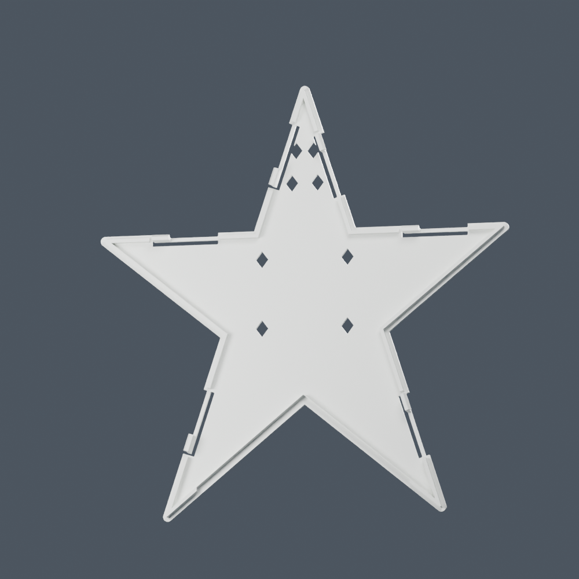
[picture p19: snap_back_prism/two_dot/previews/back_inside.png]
Back with the six preferred latches


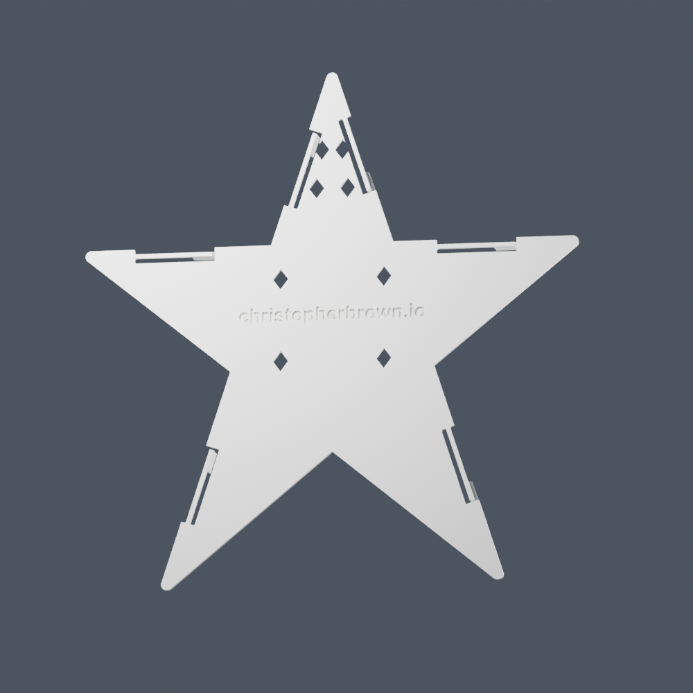
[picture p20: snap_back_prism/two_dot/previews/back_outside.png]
Outside of the marked cover


Rebuild by running `python3 snap_back_prism/two_dot/prepare.py`, then send the definitions in `build_blender.py` through Blender MCP: call `setup()` and `build_body()`, then resend the definitions, call `restore()`, `build_back()`, and `finish()`. The mark uses `/System/Library/Fonts/Supplemental/Arial Bold.ttf` on macOS; update the font path if rebuilding elsewhere. Run `validate_and_package.py`, then reimport its cleaned STLs through `restore()` and `import_canonical()`. Re-slice each changed package in Bambu Studio. To recreate previews, send `preview_blender.py` after the build definitions and `restore()`, call `setup_studio()` once, then `render_preview()` or `render_builder_mark()`.

Original model and adaptation: christopherrbrown3 / christopherbrown.io, CC BY-NC-SA 4.0. See the repository's `LICENSE`.

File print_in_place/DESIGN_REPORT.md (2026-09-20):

# Roanoke Star A1 tree topper

A single, two-color print for the Bambu Lab A1 with AMS lite: three white backing bands, 130 individually outlined tube sections, an integral tree socket, and recessed `christopherbrown.io` attribution on the back. No assembly is required.

The face and integrated mount

## Face and spacing

The star prints face-down. White tube sections and white backing bands occupy the first 1.0 mm; the surrounding dark material continues into the 4.0 mm body and rear socket. A 0.6 mm dark outline separates each white tube from its backing. Contrast defines the tubes while every front surface stays on the same plane.

All six tube paths are perpendicular offsets of the same ten edge lines. Corresponding runs remain parallel through convex tips and concave notches. The paths contain 30, 30, 30, 20, 10, and 10 tube sections. Their rounded ends and mirrored breaks interpret the photographed neon pattern; they are not a recovered historical tube schedule.

| Feature | Dimension |
|---|---:|
| Tube width / white inlay depth | 1.8 / 1.0 mm |
| Break between consecutive tube sections | 1.20 mm |
| Dark outline around each tube | 0.60 mm |
| Clear tube gaps within the three pairs | 1.937 / 1.992 / 1.865 mm |
| Clear tube gaps between paired groups | 4.195 / 4.267 mm |
| Clear gaps between the white backing bands | 1.595 / 1.667 mm |
| Body thickness | 4.0 mm |

The [spacing review](../research/SPACING_REVIEW.md) compares the geometry with the primary aerial photograph and supplied research. It supports retaining the tube positions. The backing-band width and dark outlining are choices for readability at print scale, not surveyed landmark dimensions.

## Envelope and integral socket

The complete print measures **190.960 × 199.997 × 50.836 mm** in X, Y, and Z. The front is at Z = 0, and the socket grows upward from the back. Its footprint stays behind the star's silhouette.

| Socket feature | Specification |
|---|---:|
| Axis | Star Y axis |
| Openings | Y = −32 and +48 mm |
| Length | 80 mm |
| Nominal circular clearance, lower / upper | Ø34 / Ø22 mm |
| Minimum wall | 2.4 mm |
| Bore center depth | Z = 23.4 mm |
| Roof | Two 45° facets |
| Transverse tie holes | 5 mm diamond diagonal, at Y = −18 and +22 mm |

The bore has a flat floor, vertical sides, and a pitched roof. It contains the nominal circular tapered mandrel without a horizontal ceiling. The socket overlaps the body by 0.2 mm, forming one connected dark solid. The diamond-shaped tie holes also have sloping roofs. Branch shape and fit vary; these dimensions describe available space rather than a universal tree fit.

## Recessed attribution

`christopherbrown.io` is debossed into the exposed upper-right shoulder when viewed from the back. Its 47.5 × 4.523 mm footprint is approximately 8 mm clear of both the socket and the outline. The 0.6 mm recess ends at Z = 3.4 mm, leaving 2.4 mm of material above the front inlays. Arial Bold is converted to mesh during construction; the font file is not embedded or redistributed.

Recessed attribution detail

## Two-color print project

The 3MF contains one multipart object with explicit Bambu filament assignments:

| Project filament | Geometry |
|---|---|
| 1 — dark navy or black PLA | Structural body, socket, and tube outlines |
| 2 — white PLA | 130 tube sections and three backing bands |

Both filaments feed the A1's single nozzle through AMS lite. The included configuration uses a 0.4 mm nozzle, 0.20 mm layers, four walls, five top and bottom layers, 15% gyroid infill, Arachne wall generation, supports disabled, and a prime tower. Select the actual build plate before slicing. White material is confined to the first 1.0 mm; the later body and socket print in the dark filament alone.

The earlier generic 3MF stored two display colors but omitted Bambu's part-level filament assignments. Bambu Studio imported both parts with filament 1. The exporter now records each part's `extruder` in `Metadata/model_settings.config` and includes two filament definitions. Part IDs match the referenced mesh resources, as required by [Bambu's 3MF importer](https://github.com/bambulab/BambuStudio/blob/master/src/libslic3r/Format/bbs_3mf.cpp).

Process settings also need native override metadata. Without it, Bambu Studio can replace custom values with the named system preset's defaults when opening the project. The exporter includes `different_settings_to_system`: a list of explicitly retained settings for the process, followed by entries for each filament and the printer. Its format was checked against a project saved by Bambu Studio and the official [preset-loading implementation](https://github.com/bambulab/BambuStudio/blob/master/src/libslic3r/PresetBundle.cpp). This preserves the intended walls, infill, and support settings when the system preset is resolved.

The material STLs remain an alternative: import both together as parts of one object, preserving their shared origin, then assign the two colors. The geometry-reference STL contains the complete exterior without the contrasting face pattern.

## Validation and print evidence

The [mesh report](mesh_validation.json) records independent checks against the construction profiles:

- Dark material: one watertight solid, 87,528 triangles, 77.8722 cm³.
- White material: 133 watertight solids, 77,964 triangles, 8.30384 cm³: 130 tube sections and three continuous backing bands.
- Combined exterior: one watertight solid, 9,276 triangles, 86.1760 cm³.
- Zero duplicate or zero-area triangles, and zero non-adjacent triangle-intersection candidates in both materials.
- Material overlap is negligible at numerical precision. The material union differs from the complete exterior by approximately 0.00015 mm³.
- The exported white face differs from its prepared footprint by 0.00857 mm² across 8,303.84 mm².
- The engraving-floor footprint matches the prepared lettering; minimum socket clearance is 7.947 mm.
- Zero collision with the tapered mandrel at the stated 0.05 mm radial allowance, and zero measured above-bed surface area beyond the chosen 45.05° overhang threshold.

Coplanar triangulation was canonicalized through Manifold, returned to the Blender scene, and checked without increasing intersection tolerances. The finalized Blender material meshes export byte-for-byte identical STLs to the downloadable material files. The [scene/export check](scene_export_validation.json) records both hashes and verifies that each mesh uses its intended material slot.

The 3MF is reopened programmatically to check its geometry, one-object structure, two filament definitions, part assignments, and explicit process overrides. The exact generated package was then opened and sliced in Bambu Studio 02.05.00.66 on macOS without editing the imported process or filament assignments. Each of the first five layers was visually inspected: the white bands, individual tube outlines, and separation at both lower interior corners remain visible. The sixth-layer transition to the dark body and the completed socket roof were also inspected.

An independent audit of the exported G-code confirms the A1 0.4 mm profile, 0.20 mm layers, four walls, five top and bottom layers, 15% gyroid, Arachne, Textured PEI, supports disabled, and a prime tower. Both colors occur in the model; white deposition is confined to Z = 0.2–1.0 mm, and dark material continues through Z = 50.8 mm. The 254-layer slice estimates 2 h 47 min 24 s and 70.52 g total filament, including purge and tower material. The [slicer report](slicer_validation.json) identifies the package and G-code by SHA-256; the [release status](RELEASE_STATUS.json) records the validation scope.

The owner reported a successful physical print of the earlier tube-only STL version. The white backing bands and recessed signature are subsequent changes and have not yet been physically printed. No branch-retention or load test has been performed. Digital checks do not establish those properties or verify the landmark's original dimensions.

## License and editable source

The model and geometry are licensed **[CC BY-NC-SA 4.0](../LICENSE)**, with attribution to [christopherrbrown3](https://github.com/christopherrbrown3) and [christopherbrown.io](https://christopherbrown.io). The license is included in the 3MF and model metadata. Third-party references retain their original terms.

The finalized Blender source and matching material meshes are alongside this report. Use the STL or 3MF exports for printing. The Blender file includes editable reference paths and embedded copies of the research, license, construction scripts, and validation reports. The [rebuild guide](../scripts/REBUILD.md) describes construction, export, packaging, and validation. [Research sources](../research/SOURCES.md), the [angle worksheet](../research/ANGLE_WORKSHEET.md), and the [archive search](../research/PLAN_SEARCH.md) document the evidence and its limits.

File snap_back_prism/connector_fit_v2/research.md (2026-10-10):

Research checked October 3, 2026, in response to the user's request for larger, simpler clips.

| Pattern and primary example | Evidence and practical limit | Fit for this topper |
|---|---|---|
| Protected planar spring levers — [rorys3D Robust BUCKLES](https://www.printables.com/model/281536-robust-buckles), [printed makes](https://www.printables.com/model/281536-robust-buckles/comments) | The designer describes two interlocking plates with protected compliant levers and recommends PETG. The makes include successful prints and reports of delicate arms failing under substantial tension. The page points to an updated version. | Useful evidence for broad catches, protected springs, and easy release access. A full backpack buckle would add unnecessary parts and protrusions to this back cover. |
| Simple perimeter snaps — [Extrutim Storage Box Snap-Fit Lid](https://www.printables.com/model/20961-storage-box-snap-fit-lid) | The designer supplies tight and looser lid variants, reports using PLA at 0.20 mm without supports, and notes that initial opening/closing affects fit. This is a creator report, not measured retention data. | Simple, but the star's concave perimeter makes relying on whole-wall flex less predictable than a rectangular box. |
| Rounded bead and dimple — [Dominic Böttger's printed sensor enclosure](https://dominic-boettger.com/blog/3d-printed-case-with-claude-code-openscad/) | The maker reports three PLA prints at 0.20 mm without supports, with four rounded lid bumps and matching wall dimples. | A reasonable alternative for an easy-removal cover. The tested rectangular enclosure does not establish holding force for this large star. |
| Configurable enclosure catches — [YAPP Box source](https://github.com/mrWheel/YAPP_Box), [snap parameters](https://github.com/mrWheel/YAPP_Box/blob/main/YAPP_Template_v3.scad) | Snap placement, width, and shape are parameters. Its existence alone does not establish which dimensions will work on this printer. | Supports keeping the locating fit separate from independently adjustable catches. |

[Formlabs' snap-fit guide](https://formlabs.com/blog/designing-3d-printed-snap-fit-enclosures/) recommends considering FDM layer orientation, longer compliant arms, lower engagement for easier assembly, and separate locating lugs. Its enclosure example primarily targets SLA/SLS, so its dimensions are not adopted as an FDM guarantee.

Recommendation for this topper: test a longer planar cantilever with one broad ramped hook and a simple wall window. Keep the arm within the printed layer plane and preserve face-down printing. The new tests use a 30 mm arm, an 8 mm catch, and separate guides. One and two dots identify 0.30 mm and 0.50 mm engagement. These dimensions are our engineering trial, informed by the sources, and must be judged by a new physical fit test.

Simply scaling every dimension up would also increase stiffness. The revised layout increases arm length while controlling its bending thickness and clearance. This is an inference from the cantilever geometry, not a claim that these exact samples have already been proven.

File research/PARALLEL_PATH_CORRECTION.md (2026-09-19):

# Parallel tube-path correction — 13 September 2026

The user identified visible convergence at the two lower side interior corners. A numeric audit confirmed that the independently traced paths did not have matching directions. This was a modeling defect, not merely a perspective effect in the render.

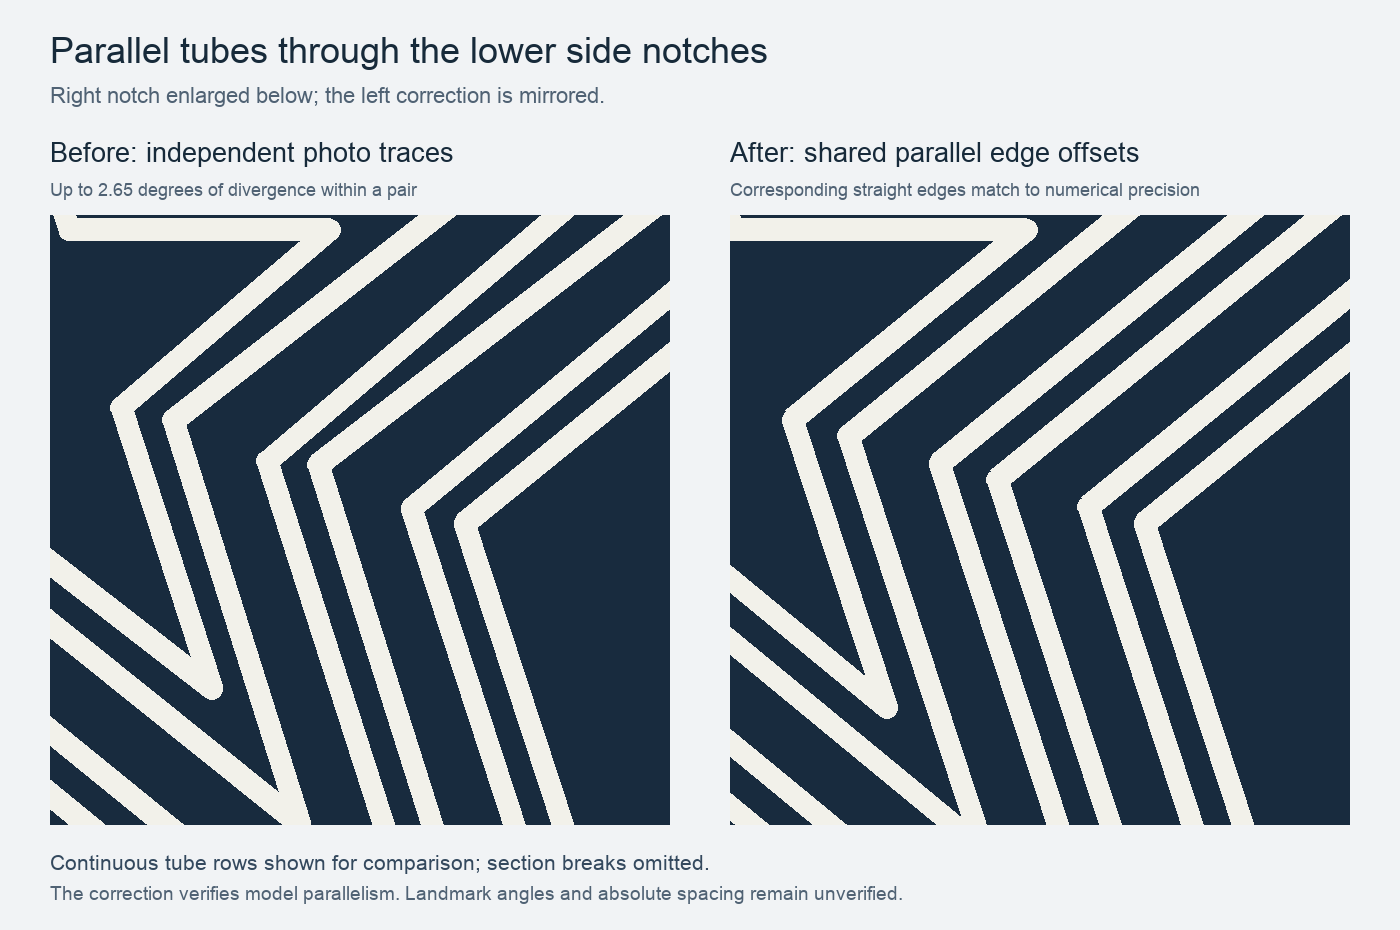
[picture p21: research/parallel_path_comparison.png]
Before and after geometry at the lower-right notch


The comparison enlarges the lower-right notch at the same scale in both panels. The left notch is its mirror. Continuous tube rows are shown to make direction and spacing visible; the printed design still has 130 individually separated tube sections.

## What was wrong

Edges are numbered clockwise from the top tip. Edge 3 runs from the right outer tip into the lower-right notch; edge 4 leaves that notch toward the lower-right tip. The matching left edges are 8 and 7.

| Pair | Prior edge-3 direction mismatch | Prior edge-4 mismatch | Prior edge-3 normal centerline gap range |
|---|---:|---:|---:|
| Paths 1 / 2 | 0.448° | 0.153° | 3.460–3.996 mm |
| Paths 3 / 4 | 2.649° | 0.246° | 2.668–4.848 mm |
| Paths 5 / 6 | 2.476° | 0.488° | 3.291–4.393 mm |

The gap ranges are endpoint projections onto the outer row's normal. They are centerline measurements, not clear edge-to-edge gaps. The two inner pairs visibly opened out along the diagonal into the notch.

## How it was corrected

All six paths now use the same ten edge directions. The outer candidate path provides the reference lines. For every nested path, those lines move inward by a single perpendicular distance; each new vertex is the intersection of its two neighboring offset lines. This keeps corresponding edges parallel and carries the constraint through both convex tips and concave notches.

Each path's offset is the least-squares fit to its previous ten vertices, measured in model millimeters. This retains a traceable relationship to the photographic reconstruction while removing its inconsistent directions. It is a design regularization, not a new measurement of the landmark. Inner vertices move by up to 4.108 mm; this is a correction to the whole nested-path construction, not just a visual adjustment to two endpoints.

| Path | Inward normal offset from outer path |
|---|---:|
| 1 | 0.000000 mm |
| 2 | 3.737158 mm |
| 3 | 9.731944 mm |
| 4 | 13.523626 mm |
| 5 | 19.590193 mm |
| 6 | 23.254967 mm |

With the 1.8 mm tube width, the straight-edge clear gaps within the three pairs are 1.937, 1.992, and 1.865 mm. The two wider gaps between pairs are 4.195 and 4.267 mm. The smallest separation between any two complete segmented white regions is 1.200 mm, at a straight-run tube interruption.

The prepared profiles have a maximum corresponding-edge direction error below 3 × 10⁻¹⁴ degrees and a normal-offset error below 2 × 10⁻¹⁴ mm. These numbers describe floating-point consistency, not achievable printer precision. Every path is a valid simple polygon and is mirrored left to right.

## Evidence and limits

The construction and measurements are reproducible with [prepare_a1_print_in_place.py](../scripts/prepare_a1_print_in_place.py). The original independently traced paths remain in [photographic_paths.json](photographic_paths.json), and the corrected coordinates and complete fit diagnostics are in [the current profile report](../print_in_place/profile_measurements.json). The [angle worksheet](ANGLE_WORKSHEET.md) and [CSV](candidate_angles.csv) now describe the corrected model paths.

Parallelism is established for the model. The absolute outline angles, frame positions, and joint schedule remain provisional because no dimensioned elevation or original tube-layout drawing has been located. The fit does not turn a photographic reconstruction into a surveyed replica.

The correction was rebuilt through Blender's GUI and exported to STL and 3MF. The owner subsequently reported a successful two-color STL print of the tube-only face. The current face retains these paths and adds white backing bands, dark tube outlines, and rear attribution. See the [spacing review](SPACING_REVIEW.md) for the follow-up assessment and the [current mesh report](../print_in_place/mesh_validation.json) for validation of the revised material regions.

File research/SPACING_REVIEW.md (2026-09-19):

# Spacing of the three paired outlines

The existing spacing is retained after review of the printed example, the source paths, and the primary aerial photograph. The three groups are already separated by clear gaps approximately twice the size of the gaps within each pair.

| Measurement, normal to a straight run | Current model |
|---|---:|
| Tube width | 1.800 mm |
| Clear gaps within pairs | 1.937 / 1.992 / 1.865 mm |
| Clear gaps between pairs | 4.195 / 4.267 mm |
| Mean centerline spacing within pairs | 3.731 mm |
| Mean centerline spacing between pairs | 6.031 mm |
| Between-pair / within-pair centerline ratio | 1.616 |

These are perpendicular distances, so a diagonal edge has the same gap as a horizontal one. Tip-to-tip distances are larger because adjacent offset lines intersect at a corner. The 1.20 mm breaks along individual tubes are a separate measurement.

## Photographic cross-check

The [City aerial image](https://www.roanokeva.gov/ImageRepository/Document?documentID=13604) remains the primary six-path tracing source. A fresh review used its original 2600 × 1461 pixel image. Two approximate vertical cross-sections through the near-horizontal shoulders locate the six illuminated centerlines at:

| Image x coordinate | Approximate image y coordinates, outside to inside | Centerline ratio |
|---|---|---:|
| 490 px | 651, 660, 675, 683, 697, 706 px | 1.67 |
| 612 px | 652, 660, 674, 683, 696, 704 px | 1.62 |

These pixel spot-checks have roughly 1–2 pixel reading uncertainty, include glow and interruptions, and are not a metric camera calibration. They corroborate the existing fit's grouping; they do not establish surveyed dimensions. Comparing adjacent lines locally reduces the effect of foreshortening, but does not remove perspective. The close [Commons neon photograph](https://commons.wikimedia.org/wiki/File:Mill_Mountain_Star_Neon_Lights.JPG) and daylight aerial views were also reviewed for the paired pattern and backing bands. Their oblique views and different lighting modes do not provide better absolute gap measurements.

The supplied research's 13 / 17 / 16 pixel within-pair intervals and 27 / 28 pixel between-pair intervals imply a **1.793 centerline ratio**, not a clear-gap ratio. Its source cross-section and camera correction are not reproducible from the supplied notes. Both estimates support wider spaces between pairs; the evidence does not justify enlarging the current geometry to one exact ratio.

## Print evidence and design choice

The owner reported a successful two-color STL print and supplied a photograph of the unengraved version. The photograph shows the paired outlines, but its perspective and lighting are unsuitable for dimensioning either the print or the landmark. It is retained privately and is not redistributed here.

At a 0.4 mm nozzle width, the clear gaps between paired tube groups are over ten nozzle widths across. The existing tube spacing is therefore retained. A wider gap can be an aesthetic preference, but would not be an established correction to the landmark geometry. The source edge directions, exact parallelism, and overall envelope remain unchanged.

## White backing bands

The subsequent face treatment adds three white bands beneath the tube pattern. Each band's outer and inner boundaries sit 2.2 mm from the corresponding tube centerlines. The resulting **clear gaps between the white bands are 1.595 and 1.667 mm**; these are different from the 4.195 and 4.267 mm distances between tube edges. A 0.6 mm dark keyline surrounds each tube so the white tube sections remain visible against the white bands. All visible regions are flush to the print bed and use the same two materials.

The 2.2 mm band margin and 0.6 mm keyline are choices for a readable, printable miniature. They are not measured dimensions of the landmark's backing panels. The actual tube positions are preserved.

See [profile_measurements.json](../print_in_place/profile_measurements.json) for the full paths and [USER_RESEARCH_REVIEW.md](USER_RESEARCH_REVIEW.md) for the distinction between photographed centerlines and clear gaps.

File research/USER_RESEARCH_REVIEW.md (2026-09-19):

# Review of supplied research and print reference — 12 September 2026

The user's two-color Christmas tree topper remains the target. The new desk-print photograph is an appearance reference. Its lighting enclosure and electrical design are outside the chosen design. The original Markdown is preserved without alteration. The photograph is represented by its source hash and provenance in [user_provided](user_provided/PROVENANCE.json); the image itself is excluded from the public repository.

## Findings to retain

- Three structural star frames are documented by the [City of Roanoke](https://www.roanokeva.gov/1329/Roanoke-Star).
- The all-white photographs support six dominant visible contours arranged in three close pairs, with larger spaces between pairs. The current candidate already models that topology. This is a visible-pattern interpretation, not a count of every physical glass tube or circuit.
- The supplied desk-print photo reinforces the dark face / white paired-outline appearance. It is oblique and cannot independently establish face-on angles, exact proportions, or spacing.
- The 88.5-foot star height has multiple historical and official sources. The supporting tower's 100-foot height is a separate dimension.
- Original drawings and recent engineering assessments remain valuable leads. They have not yet supplied verified vertex coordinates.

## Corrections and qualifications

| Supplied claim | Review | Consequence for CAD |
|---|---|---|
| The 84.5-foot width definitively proves the actual Star is not regular | The Smithsonian inventory records **approximate** dimensions. The [city art catalog](https://www.artworkarchive.com/profile/roanoke-arts/artwork/roanoke-star) gives **1062 × 1200 inches**, equivalent to 88.5 × 100 feet, without an engineering elevation or clear axis explanation. If 84.5 feet is confirmed as frontal star width, it is incompatible with an upright regular pentagram of height 88.5 feet. | Keep 84.5/88.5 as an explicit current modeling assumption; resolve the conflicting measurement sources before treating it as exact. Do not silently choose 100 feet either. |
| 0°, ±30°, ±60° edge families and a 60° apex | A photo-derived hypothesis, without the source coordinates, camera calibration, correction transform, residuals, or uncertainty needed to reproduce it. An apparent angle in a low-angle/oblique photo is not a physical angle. | Do not replace the candidate's inferred 36.66° apex with 60° on this evidence. Neither value is verified as the landmark's angle. |
| Inter-band **clear gap** is about 1.8 times paired-track spacing | The supplied pixel positions are **centerlines**. Their intervals are 13, 17, 16 pixels within pairs and 27, 28 pixels between pairs. The mean ratio is 27.5 / (46/3) = **1.79348**. | This is a ratio of cross-section centerline intervals. It is not a clear edge-to-edge gap ratio. Subtract the half-widths of adjacent lines to obtain clear gaps, and measure normal to the local edges in a metrically corrected image. |
| Frame sizes 1.00 / 0.74 / 0.43 | Useful hypotheses, but no reproducible fit data or dimensioned source accompanies them. The present candidate uses different independently traced paths. | Preserve the estimates as research; do not silently overwrite paths or force all nested contours to be scaled copies. |
| “3–5 sets” explains the electrical grouping | The city gives that wording, but the proposed interpretation of circuitry versus fabricated pieces is not established by a wiring/shop drawing. | Avoid claiming a complete historical tube or circuit layout. |

A low-angle photograph can foreshorten the vertical dimension and widen the apparent apex; yaw and roll add further distortion. A free homography can fit different underlying shapes to the same photo. Even several unconstrained homography overlays are insufficient proof of metric accuracy. See [ACCURACY_AUDIT.md](ACCURACY_AUDIT.md).

## Interior and exterior angles

[ANGLE_WORKSHEET.md](ANGLE_WORKSHEET.md) reports every vertex of the **current candidate**, with full calculations for all six paths in [candidate_angles.csv](candidate_angles.csv). Interior angle, signed exterior turn, and outside sector are separately defined. The worksheet is a transparent record of the model, not a recovered original specification.

## Design carried forward

The latest model in [print_in_place](../print_in_place/DESIGN_REPORT.md) has 130 white inlay sections along six paths in three pairs, a continuous dark backing, and an integral hidden tree socket. The user chose a single print with no assembly on a Bambu A1 with AMS lite. The white solids and dark body fuse in the same print; no removable inserts or mount fasteners are needed. The reference desk print's individual dash lengths are not treated as original neon segment dimensions. No LED enclosure, wiring, diffuser, or electronics has been added.

Both actual color meshes in the A1 model report zero non-adjacent triangle-intersection candidates, and independent checks validate the fused solid and material coverage. The owner subsequently reported a successful two-color STL print of the tube-only face. The current face adds three white backing bands and dark tube outlines, with recessed attribution on the back. The [spacing review](SPACING_REVIEW.md) documents that change and distinguishes it from the earlier physical print. Mesh validity does not establish landmark fidelity; the exact historical geometry remains unresolved.

## Provenance of the secondary print

The supplied kitchen-counter photograph has no verified model page or creator attribution in the task. The separately linked [MakerWorld model by Higgins](https://makerworld.com/en/models/380234-roanoke-star) calls itself a recreation and supplies no engineering provenance. It was not used as a dimension source or imported into the CAD. The page was publicly viewable; a failed automated fetch was not evidence of a paid model.

See [PLAN_SEARCH.md](PLAN_SEARCH.md) for archive findings and the scope of the material examined.

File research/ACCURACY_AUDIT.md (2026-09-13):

# Accuracy audit — 10 September 2026

**Finding: photographic fit does not establish exact landmark geometry.** This audit documents the constraints and limitations of the reconstruction used as the model’s starting point.

## The main methodological weakness

The city photograph was traced accurately in image space, but the inferred face-on geometry depends on assumed symmetry, level shoulders, approximate parallelism between paired tube edges, and a published overall aspect ratio. The pair-parallelism assumption has not been established by a drawing or measured landmark dimensions.

The later drone comparison fitted a free projective transform. Such a transform can absorb changes in the underlying face-on proportions. A lower reprojection error therefore supports image-space consistency, but does **not** independently prove correct apex angle, shoulder height, lower-leg length, or nested spacing.

`audit_projective_ambiguity.py` constructs three example shapes with the same bilateral symmetry, horizontal shoulders, and 84.5/88.5 overall aspect ratio. Their apex angles are 30.68°, 36.66°, and 44.43°. Each maps exactly back to the current reconstruction through a projective transform, and therefore can retain the same photo reprojection when the camera homography is refitted. Numerical round-trip error is below 5×10⁻¹⁴ mm.

These examples are a mathematical counterexample, **not a confidence interval and not proposed replacement designs**. Additional physical constraints, including verified edge parallelism or calibrated camera geometry, could distinguish them. The current evidence has not established those constraints strongly enough to claim exactness.

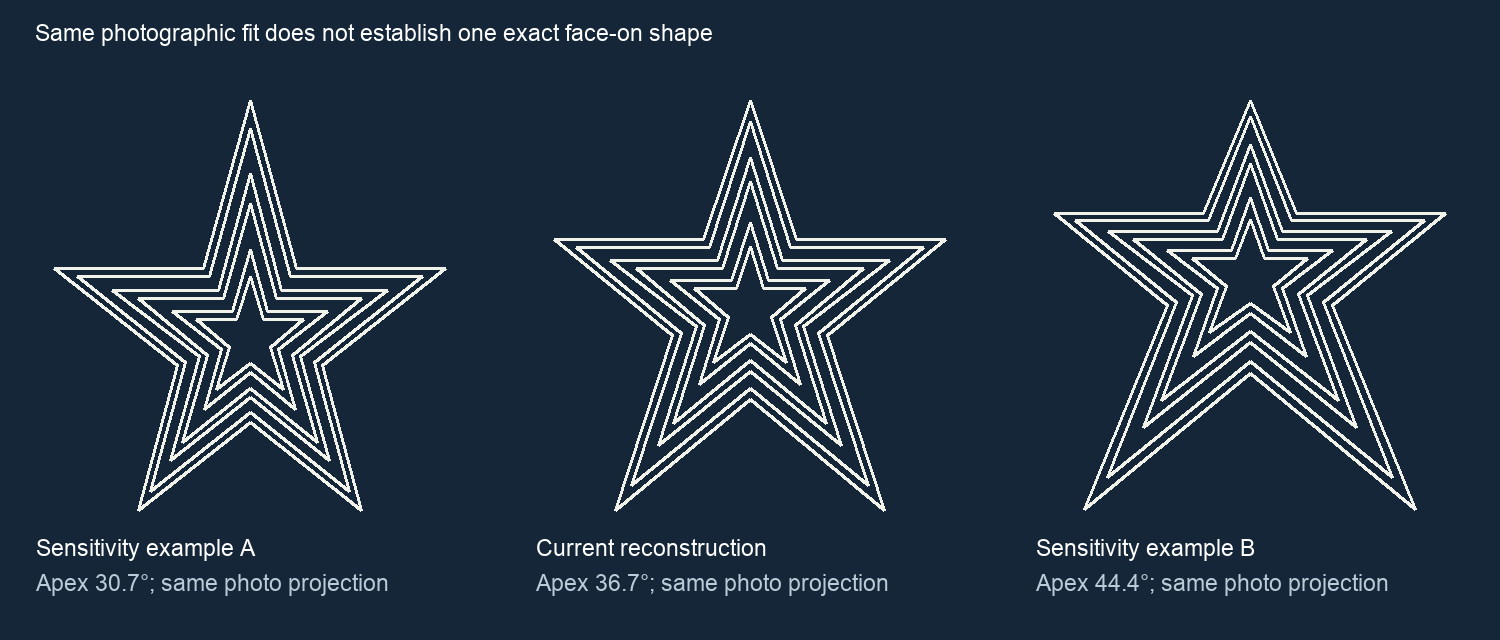
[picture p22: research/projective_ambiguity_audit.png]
Projective ambiguity


## What is actually supported

- The [City of Roanoke](https://www.roanokeva.gov/1329/Roanoke-Star) gives the star height as 88.5 feet and describes three nested frames carrying multiple neon tube sets.
- The [Smithsonian inventory](https://siris-artinventories.si.edu/ipac20/ipac.jsp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) gives **approximate**, not survey-certified, dimensions of 88.5 × 84.5 feet.
- The [city art catalog](https://www.artworkarchive.com/profile/roanoke-arts/artwork/roanoke-star) records 1062 × 1200 inches, or 88.5 × 100 feet, without a dimensioned elevation explaining the axes. The width-related discrepancy is unresolved. The current 84.5/88.5 aspect ratio is an assumption supported by one approximate inventory, not an independently verified measurement.
- The city aerial visibly contains six illuminated contours grouped in three pairs in its all-white configuration. This does not establish the total number or exact layout of all physical neon tubes in every color mode.
- Low-angle and oblique photographs require perspective treatment. Copying their apparent proportions directly would also be wrong.

## Additional searches completed

Searches covered original 1949 plans/blueprints, Kinsey drawings, CAD, engineering/renovation plans, historic nominations, the Virginia Room finding aid, and later inspection/maintenance records.

The [DHR nomination](https://www.dhr.virginia.gov/VLR_to_transfer/PDFNoms/128-0352_Roanoke_Star_1999_Final_Nomination.pdf) supplies history and overall dimensions, but its available exhibits are location/site maps, not a dimensioned star elevation. The [1982 first-person account by Edward C. Moomaw](https://www.virginiaroom.org/digital/files/original/67/6354/JHSWV_11_02_1982.pdf) identifies the construction participants but did not provide a usable coordinate drawing in the material examined. No public dimensioned star elevation was located in these searches; this is not a claim that no drawings exist.

## Measurement limits

A dimensioned front elevation or fabrication drawing establishes constraints that the photographs alone cannot. Relevant measurements include the heights and horizontal offsets of each frame's ten vertices, tube offsets within each frame, and the distinction between the steel/aluminum silhouette and tube centerlines.

A calibrated survey or a sufficiently controlled photograph set can also constrain the geometry, but should report camera calibration, perspective model, measurement residuals, and uncertainty. A drone gimbal-angle tag by itself is insufficient.

The repository retains the current candidate and full provenance. No further shape has been selected merely because it looks more plausible, and no outside organization has been contacted.

## Update — 12 September 2026

The [new user research review](USER_RESEARCH_REVIEW.md) retains the three-pair topology and identifies the supplied 60° apex as an unverified photo hypothesis. It corrects the proposed 1.8× **clear-gap** rule: the supplied pixels describe centerline intervals, so that number is not a clear-gap ratio. The [angle worksheet](ANGLE_WORKSHEET.md) exposes all candidate angles with explicit conventions. The [plan search](PLAN_SEARCH.md) records the examined archival sources and their coverage; no dimensioned Star elevation was found.

The continuous-insert candidate's pending Blender repair has now passed the existing digital mesh and assembly checks, including zero self-intersection candidates. The user subsequently requested individually visible tube sections, so a segmented-tube revision is in progress. The repair does not resolve landmark geometry.

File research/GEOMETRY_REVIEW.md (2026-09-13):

# Photograph review and perspective reconstruction

This document records the photographic evidence and reconstruction method. The [accuracy audit](ACCURACY_AUDIT.md) explains the limits of inferring physical geometry from uncalibrated photographs.

## Published dimensions and structure

The [City of Roanoke](https://www.roanokeva.gov/1329/Roanoke-Star) describes an 88.5-foot star with three nested frames, each carrying three to five sets of clear neon tubing. The [Smithsonian inventory](https://nmaahc.si.edu/object/siris_ari_334963) records 88.5 feet high by 84.5 feet wide. This gives a width of **190.96 mm at 200 mm height**.

The [Virginia Department of Historic Resources nomination](https://www.dhr.virginia.gov/VLR_to_transfer/PDFNoms/128-0352_Roanoke_Star_1999_Final_Nomination.pdf) describes the substantial steel lattice support. This rear tower is omitted from the topper and replaced with an integrated tree socket.

## Photographs actually examined

The expanded comparison includes the following distinct views, with different uses rather than equal geometric weight:

| Reference | View and use |
|---|---|
| [City aerial, original 2600 × 1461](https://www.roanokeva.gov/ImageRepository/Document?documentID=13604) | Primary measurement source: nearly frontal white illumination, six visible paths in three pairs. Mild perspective is corrected. |
| [Ben Schumin aerial, 13 June 2024](https://www.schuminweb.com/photo_features/aerial-view-of-the-roanoke-star/) | Independent high-resolution 8064 × 5376 check of frame vertices and support depth. Oblique and viewed from above. |
| [Schumin travel series](https://www.schuminweb.com/life-and-times/adventures-in-tennessee-part-7/), image 393 | Ground-level oblique, framing and tubing details; not directly traced for proportions. |
| Same series, image 399 | More distant aerial, overall proportions. |
| Same series, image 400 | Oblique aerial from one side. |
| Same series, image 401 | Oblique aerial from the opposite side. |
| Same series, image 429 | Very distant city/ridge view, recognizability and silhouette. |
| Same series, image 430 | Overhead/edge view, rear support and depth. |
| [Wikimedia: Roanoke star](https://commons.wikimedia.org/wiki/File:Roanoke_star.jpg) | Low-angle close view; tube and frame placement only. |
| [Wikimedia: Mill Mountain Star Neon Lights](https://commons.wikimedia.org/wiki/File:Mill_Mountain_Star_Neon_Lights.JPG) | Low-angle colored illumination; color circuits and tube placement. The colored mode does not illuminate the same visible paths as the all-white view. |
| [Visit Virginia's Blue Ridge](https://www.visitroanokeva.com/things-to-do/attractions/roanoke-star/), patriotic aerial | Additional oblique aerial proportion check. |
| City image 13600 | Rear steel support. |
| City image 13601 | Underside, deliberately excluded from frontal tracing. |
| City image 13602 | Low-angle front, deliberately excluded from frontal tracing. |
| City image 13603 | Distant night appearance. |

The city screenshots and the original city aerial are the same view and are not counted as different photographs. Six visible illuminated contours are an interpretation of the all-white display at this scale; they are not a claim that the landmark contains only six individual neon tubes.

## Perspective treatment

1. Extract six bright centerline paths from the original city aerial. Radial peak detection provides 596 accepted six-peak samples. Each path's ten straight segments are fitted independently; segment intersections define the vertices. The median-quality edge fitting is approximately 0.19–0.25 image pixels RMS per path. This is tracing precision, not physical dimensional accuracy.
2. Fit a projective correction using bilateral symmetry, horizontal shoulder segments, and approximately parallel corresponding segments within each pair. Anchor the overall width-to-height ratio to the published dimensions. Do not assume that all six stars are scaled copies.
3. Average opposing vertices to remove photographic asymmetry. The largest resulting adjustment is 1.38 mm on the 200 mm normalized reconstruction.
4. Reproject the three outer frame paths onto a separate high-resolution drone image. The revised fit has 15.81 pixel RMS error versus 29.10 pixels for the earlier geometry, about a 46% reduction. This is an independent visual consistency check; differences between a lit tube centerline and a steel frame edge, image distortion, and manual landmark selection remain.
5. Use ground-level photographs to check tubing and support details, not to dictate frontal angles. The 2024 drone file records a 14.3° downward gimbal angle, but metadata alone was insufficient to determine a precise front-plane correction and was not used as an exact calibration.

This is a measured photographic reconstruction, not a surveyed replica. No engineering drawing establishing every vertex was located. Numerical fit results must not be interpreted as a guaranteed millimeter accuracy of the real landmark.

## Relationship to the print model

The [photographic path record](photographic_paths.json) preserves the centerline coordinates used as input to the current design. The [parallel-path construction](PARALLEL_PATH_CORRECTION.md) derives consistent inward offsets from those coordinates. Current manufacturing dimensions, the integrated mount, and validation are documented in the [A1 design report](../print_in_place/DESIGN_REPORT.md).

The [original reconstruction data](accurate_light_paths.json) supports the perspective audit. Reference photographs and annotated photo comparisons are linked through the [source inventory](SOURCES.md); they are not redistributed in the repository.

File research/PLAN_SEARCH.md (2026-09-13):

# Original-plan search — 10–12 September 2026

**No dimensioned original Star elevation, complete shop drawing, or modern measured elevation was located in the material examined.** This does not establish that no plans survive. There is still no archival basis for assigning exact interior/exterior angles, notch positions, or nested frame offsets.

## City of Roanoke Engineering

The [Engineering Division](https://www.roanokeva.gov/354/Engineering) identifies archived survey/plan records, GIS links to parcels, and Facilities' shop-submission and photograph files. The public [EngMapsandPlans Laserfiche repository](https://laserfiche.roanokeva.gov/WebLink/Browse.aspx?dbid=0&repo=EngMapsandPlans) is searchable without contacting staff.

The General Search term `star` returned 92 entries, including both folders and documents. All five result pages were reviewed by title. Most concern subdivisions, businesses, or property surveys. The potentially relevant **City of Roanoke (46)** was opened and visually inspected: [document 11101](https://laserfiche.roanokeva.gov/WebLink/DocView.aspx?id=11101&dbid=0&repo=EngMapsandPlans) is a one-page land-acquisition plat, not the Star.

The term `Mill Mountain` returned 153 entries; the first 100 titles were screened. Results include park surveys, a transmitter tower, zoo buildings, roads, the Greenway, and subdivisions. [Mill Mountain Park, document 19484](https://laserfiche.roanokeva.gov/WebLink/DocView.aspx?id=19484&dbid=0&repo=EngMapsandPlans), was opened and visually inspected: drawing **2192-B** is a park land/topographic survey, not a front elevation of the Star. Search-title screening does not prove that every sheet or unindexed file lacks a Star detail. Internal Facilities records may not be represented in this public repository.

The historic nomination identifies parcel **4050306**. That is a historical identifier, not independently verified as a current parcel number. The current Engineering page lists Luke E. Pugh, City Engineer, at 540-853-5201. No call or message was made.

## DHR and National Park Service

The [DHR nomination for resource 128-0352](https://www.dhr.virginia.gov/VLR_to_transfer/PDFNoms/128-0352_Roanoke_Star_1999_Final_Nomination.pdf) is an actual 17-page PDF. Its last exhibits are site/location maps, visually checked as images.

- PDF page 15 is printed exhibit page 11, **Exhibit A**, a tax parcel map.
- PDF page 16 is printed exhibit page 17, **Exhibit G**, the revised 1950 Mill Mountain Park survey.
- The available file does **not** include Exhibits B–F. Their contents are unknown; the gap is a reason to request the complete file, not evidence that those exhibits contain engineering drawings.
- The photo list specifies Anne Stuart Beckett, 6 July 1999, negative **17627**, and north / south-and-west elevation views.
- The acknowledgments name Ken Harris and Bill Liles of City Engineering.

The [NPS asset record, NRIS 99001375](https://npgallery.nps.gov/AssetDetail/NRIS/99001375), links to nomination and photo assets. At retrieval, both links returned the same one-page **NOT DIGITIZED** placeholder, rather than the full files. The two locally retained PDFs are explicitly named `*_NOT_DIGITIZED.pdf`. They provide no geometry. The [DHR Archives](https://www.dhr.virginia.gov/programs/dhr-archives/) are a lead for the complete physical/oversized record.

## Virginia Room holdings

The [vertical-files finding aid](https://www.virginiaroom.org/digital/files/original/13/1792/VerticalFiles.2.pdf) lists these actual topical files:

- PDF page 10: **Business & Industry — VA — Roanoke — Roy C. Kinsey Sign Company**.
- PDF page 10: **Business & Industry — VA — Roanoke — Roanoke Iron & Bridge Works**.
- PDF page 52: **Mountains — VA — Roanoke — Mill Mountain**.

The index confirms files exist; their contents have not been inspected and cannot be described as holding Star plans. The [maps/architectural-plans finding aid](https://www.virginiaroom.org/digital/file/7400) includes 1941 **Observation Tower for Roanoke, Virginia** sheets and a Roy C. Kinsey residence drawing. Neither is a 1949 Star drawing. The Dr. John Kern finding aid was also checked without locating an explicit Star entry.

Edward C. Moomaw's [1982 account, “How the star was turned on”](https://www.virginiaroom.org/digital/files/original/67/6354/JHSWV_11_02_1982.pdf), was visually examined in full at PDF pages 90–92 / printed pages 88–90. It identifies Roy C. Kinsey Sign Company and **Robert L. Little** of Roanoke Iron & Bridge Works, whereas DHR uses **Robert R. Little**. It contains history and a photograph, not a dimensioned elevation. Search both initials.

## Modern studies and fabrication history

[WDBJ's 2023 report](https://www.wdbj7.com/2023/05/10/roanoke-considers-restoration-or-replacement-mill-mountain-star/) and [WSLS's May 2023 report](https://www.wsls.com/news/local/2023/05/18/roanoke-leaders-to-consider-refurbishment-plan-for-mill-mountain-star/) establish a contemporary restoration discussion. The reported 2019 inspection and 2021 internal study remain leads: their complete reports, appendices, and dimensioned attachments were not retrieved. Public Parks advisory-board pages and indexed WordPress media did not expose those engineering reports in the searches made.

The [WDBJ interview transcript preserved by Virginia Tech](https://scholar.lib.vt.edu/VA-news/WDBJ-7/script_archives/99/1199/112899/112899.m.htm) describes assembly flat on the airport ground, disassembly, and re-erection on the mountain. This supports seeking fabrication/erection records. It does not itself show a drawing or establish an angle.

## Next evidence to obtain

Priority is a dimensioned front elevation for all three frames, or a reliable set of surveyed vertex coordinates. Ask which dimensions refer to frame edges, tube centerlines, or the overall visual envelope. The Smithsonian's original **IAS VA000441** measurement worksheet is particularly useful for resolving the approximate 84.5-foot width against the city art catalog's 100-foot second dimension.

The search coverage above records the publicly examined material. No archive correspondence is represented as completed research.

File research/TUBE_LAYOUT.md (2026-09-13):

# Roanoke Star neon tube segmentation: bounded photo research

Research question: where do the physical neon tube sections appear to break on the Mill Mountain / Roanoke Star, especially the six bright all-white contours arranged in three close pairs?

This is a photographic fabrication aid, not a survey or a wiring diagram. The exact historical tube schedule was not found. The notes below distinguish what is visible from what is a safe modeling assumption.

## Sources and evidentiary weight

* **Best close-up source:** Ben Schumin's night photo set, [The Roanoke Star, Night](https://www.schuminweb.com/photography/roanoke-star-night/). The page itself says that, except for the red ring in that display, each ring is lit by two rows of tubing; it also says that many smaller tubes form each ring and shows close views of a top apex, lateral point, lower point, corners, and underside. The individual full-size image URLs used for the observations are [089 (top apex)](https://files.schuminweb.com/photography/roanoke-star/full-size/089.jpg), [091 (apex and many short pieces)](https://files.schuminweb.com/photography/roanoke-star/full-size/091.jpg), [092 (upper side / apex)](https://files.schuminweb.com/photography/roanoke-star/full-size/092.jpg), [098 (paired white tubes)](https://files.schuminweb.com/photography/roanoke-star/full-size/098.jpg), [100 (outer lateral tip)](https://files.schuminweb.com/photography/roanoke-star/full-size/100.jpg), [101 (lower outer tip)](https://files.schuminweb.com/photography/roanoke-star/full-size/101.jpg), [102 (notch / corner hardware)](https://files.schuminweb.com/photography/roanoke-star/full-size/102.jpg), and [103 (apex / corner hardware)](https://files.schuminweb.com/photography/roanoke-star/full-size/103.jpg).
* **Best all-white contour source:** the City of Roanoke's [13604 aerial image](https://www.roanokeva.gov/ImageRepository/Document?documentID=13604), recorded during analysis as `research/references/city_aerial_original.jpg` (reference original not distributed). It is nearly frontal enough to establish six dominant bright paths grouped as three close pairs, but the star is too small and overexposed for reliable tube-joint positions.
* **Independent all-white close source:** Ben Schumin's [Roanoke Star in white](https://commons.wikimedia.org/wiki/File:Roanoke_Star_in_white.jpg), dated 22 April 2007. It confirms the white display and paired contours, but the available image still does not resolve every glass joint around the complete star.
* **Useful colored close source:** [Mill Mountain Star Neon Lights](https://commons.wikimedia.org/wiki/File:Mill_Mountain_Star_Neon_Lights.JPG), 17 November 2008, 2,592 × 1,944. Its red/white/blue close view makes the small dark breaks and tube supports easiest to see. It is evidence for physical segmentation and mounting, not for which circuits are energized in the all-white display.
* **Daylight / aerial sources:** the local Ben Schumin daylight and 2024 aerial photographs are useful for steel channel depth, rear scaffold, and perspective. They do not expose neon glass-joint locations and should not be used to invent a tube schedule.

## What the close-ups actually show

### Tube count and pair arrangement

The close-ups show two parallel illuminated tubes following a ring/frame in the white and blue rings. This agrees with Schumin's caption that the rings other than the red one use two rows. Together with the City's nearly frontal white aerial, the practical all-white topology is six visible tracks: three structural bands, each represented by a close pair.

This does **not** mean six physical glass tubes. Each visible track is made from many shorter sections. The City's 2,000-foot total and its “sets” wording do not publish the individual piece count or electrical grouping.

### Long straight runs

On the upper arm and outer-point close-ups (images 100 and 101), the long straight portions visibly contain multiple short pieces, with the joints away from the geometric point. A coordinate check on the bright lower row of the outer upper-right horizontal arm in the Wikimedia close-up gives approximate endpoints at x=1545 and x=2285, and clear dark interruptions at x=1736, 1915, and 2092. Those fall at about 0.258, 0.500, and 0.739 of the horizontal x-span, suggesting four visible pieces on this particular long run. This is stronger evidence than a generic two-joint 30%/65% schedule for that arm, although the dark interruptions could include connector/terminal hardware or support occlusion.

The same photograph shows that section lengths are not uniform: the first and last pieces on this arm are shorter than the middle pieces. Other sloping legs read as two or three sections, but their exact positions are less clear.

On the sloping legs in images 091, 092, and 103, the same scale is visible: generally two or three sections per straight leg. The shortest inner-star legs sometimes read as one long section plus a shorter terminal section, but image perspective and glow make an exact count uncertain.

These are approximate proportions measured by eye from the close photographs. They are a useful starting schedule, not a claim about the original glass-shop dimensions.

### Apexes and outer tips

The top apex close-ups (089, 091, 092, 103) show a sharp, fully illuminated point. The obvious dark breaks occur down the sloping legs, typically around the middle portions of the legs, rather than as a visibly open gap at the apex itself. Each parallel row follows the same sharp outline.

The outer lateral point (100) and lower outer point (101) show the same behavior: the two rows reach the point and turn sharply into the adjoining leg. The point region is not a long uninterrupted bend; the straight legs have their own visible section boundaries close to the corner. A miniature should therefore keep the light visually continuous through the point while allowing a short section or joint treatment on each adjoining straight leg.

The photos do not prove whether a given corner uses one custom bent glass piece, two pieces meeting at an electrode/connector, or a hidden overlap behind the aluminum channel. Do not encode a precise “joint exactly at every vertex” claim from these images.

### Shoulders and concave notches

Image 100 shows the upper lateral arm ending in a sharp outer tip, while image 102 shows a concave notch where a ring turns from a horizontal run into a steep leg. The tube rows follow the metal member through these tight corners; the dark marks visible near the turns are consistent with tube ends/supports and are not all individually distinguishable as electrical breaks.

The safe physical reading is: straight glass sections terminate close to the corners, and the corner is a deliberately sharp fabricated transition. It is unsafe to infer exact offsets or a universal corner piece length from the low-angle view.

## Are the two paired runs synchronized?

They do not appear to be synchronized. In the close white/blue pair views (098, 102, and 103), a dark break on one row is visibly displaced along the run from the corresponding break on its neighboring row. The colored close-up (especially the red and white paired runs) repeats the same impression. Some displacement could be due to oblique perspective and the fact that supports partially occlude one row, so the exact offset is not measurable. The evidence supports **staggered or at least non-guaranteed break positions**, not a shared break line across both tubes.

For a printable display model, a reasonable photo-faithful convention is to offset joints in the two rows by roughly 5–15% of the straight-run length, then vary the offset slightly by leg. That range is an implementation inference from the apparent close-up displacement, not an archival dimension.

## Suggested section schedule for the topper

If the parent model needs visibly individual tube sections, use this as a constrained visual schedule:

| Region of each visible track | Starting schedule | Confidence |
|---|---|---|
| Long horizontal upper arm | One measured example: 4 pieces; joints near ~0.258, ~0.500, and ~0.739 of the horizontal x-span | Moderate for the photo coordinates, low for generalizing to every arm |
| Long sloping outer legs | 2–3 pieces; roughly quarter-to-two-fifths run lengths | Moderate |
| Apex-to-shoulder steep legs | 2–3 pieces; avoid a conspicuous gap at the apex | Moderate |
| Short inner-star legs | 1–2 pieces where scale leaves little room | Low to moderate |
| Immediately around any tip/notch | Short terminal pieces at each adjoining leg; maintain a lit visual connection through the corner | Moderate as a fabrication convention, low as an exact historical claim |

For each pair, keep the overall paths parallel and close, but do not assume a shared global dash phase. The measured red horizontal example has interruptions that appear approximately aligned between the paired rows, while Schumin's oblique close-ups suggest phase differences elsewhere. Supports, parallax, and tube glow make a universal “stagger every pair” rule too strong. Vary section boundaries by run, and use the measured 0.258/0.500/0.739 pattern only for the documented arm unless additional evidence is available.

## What should not be claimed

* No public source found here gives exact break coordinates, section counts per leg, tube diameters, or electrical circuit boundaries.
* The City aerial establishes the six visible white contours, not six individual tubes and not the full hidden inventory of glass sections.
* RGB images can show a different subset of energized rows; they are unsuitable for counting the all-white paths.
* Low-angle photos distort longitudinal positions. A break that appears offset between rows may include perspective, support occlusion, or parallax; use the repeated pattern only as qualitative support for staggering.
* Replica products, MakerWorld/FSX models, and decorative artwork are not geometry evidence.

## Practical conclusion

The most defensible miniature treatment is six individually modeled visible tracks grouped as three close pairs, with each long straight leg split into approximately 2–3 sections, short terminal pieces near corners, and deliberately staggered joints between the two rows of each pair. Preserve continuous light at apexes, outer tips, and notches. Treat exact joint locations as a visual approximation until a dimensioned fabrication or restoration drawing is found.

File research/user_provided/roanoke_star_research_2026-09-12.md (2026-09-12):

# Roanoke Star Reconstruction Research

**Subject:** Roanoke Star / Mill Mountain Star, Roanoke, Virginia  
**Purpose:** Consolidated research for a geometrically faithful reproduction, especially an all-white 3D-printable version  
**Status:** Working research summary. Documented facts are separated from photo-derived inferences and rejected hypotheses.

---

## 1. Executive summary

The Roanoke Star is best understood as **three nested structural star frames** mounted on a steel support tower, with multiple neon tube runs attached to those frames.

For reproduction purposes, the most important visual finding is:

> **The all-white configuration shows six dominant illuminated star contours arranged as three close pairs.**

The spacing hierarchy is:

> **[two close lines] — larger gap — [two close lines] — larger gap — [two close lines]**

This is the single most important geometry correction from earlier attempts. The six visible contours should **not** be modeled as six evenly scaled stars.

The strongest documented overall dimensions found so far are:

- **Star height:** ~88 ft 6 in
- **Star width:** ~84 ft 6 in
- **Star depth:** ~2 in
- **Support tower height:** ~100 ft
- **Support width:** ~64 ft 10 in
- **Support depth:** ~29 ft 2 in
- **Foundation depth:** ~6 ft 6 in
- **Star weight:** ~10,000 lb
- **Support steel weight:** ~60,000 lb
- **Concrete foundation weight:** ~500,000 lb
- **Total neon tubing:** ~2,000 linear ft

The width measurement is especially important because it shows that the actual Star is **not a regular pentagram**. A mathematically regular five-point star that is 88.5 ft tall would be about 93.05 ft wide, substantially wider than the Smithsonian survey measurement of ~84.5 ft.

The most plausible current reproduction target is therefore:

- all-white lighting
- three structural star bands
- two prominent visible tube tracks per band
- large gaps between the three structural bands
- vertically elongated overall silhouette
- approximately 30°/60° edge families, based on photo measurement
- no reliance on decorative replicas or flight-simulator geometry

---

## 2. Strongest documented dimensions

### Smithsonian / Save Outdoor Sculpture survey

The Smithsonian American Art Museum's **1995 Save Outdoor Sculpture** record, inventory **IAS VA000441**, provides the best dimensional survey found so far.

Recorded approximately as:

| Element | Dimension |
|---|---:|
| Star height | **88 ft 6 in** |
| Star width | **84 ft 6 in** |
| Star depth | **2 in** |
| Support height | **100 ft** |
| Support width | **64 ft 10 in** |
| Support depth | **29 ft 2 in** |
| Base / foundation entry | **17⅔ in × 68 ft 10 in × 6 ft 6 in** |

The base line is difficult to interpret because the axis order is not obvious. Preserve it as a raw catalog measurement rather than treating the 17⅔-in dimension as a confirmed engineering thickness.

Source:

- Smithsonian SIRIS / Inventories of American Painting and Sculpture, **IAS VA000441**  
  https://siris-artinventories.si.edu/

### Near-contemporary plaque / historical publication

The 1957 *Roanoke Diamond Jubilee Historical Program* reproduces the well-known Star plaque and gives:

- Star height: **88½ ft**
- Supporting steel structure: **100 ft**
- Star weight: **10,000 lb**
- Supporting steel weight: **60,000 lb**
- Foundation weight: **500,000 lb**
- Foundation depth: **6½ ft**
- Neon tubing: **2,000 ft**

Source:

- Virginia Room, *Roanoke Diamond Jubilee Historical Program*  
  https://www.virginiaroom.org/digital/files/original/12/3984/Jubilee.pdf

### National Register nomination

The 1999 National Register nomination repeats the major historic dimensions:

- star height ~88.5 ft
- star weight ~10,000 lb
- tower height ~100 ft
- tower weight ~60,000 lb
- foundation weight ~500,000 lb

It also confirms:

- Roy C. Kinsey Sign Company as the principal sign/star contractor
- Roanoke Iron & Bridge Works as structural support designer
- DHR resource number **128-0352**

Source:

- Virginia Department of Historic Resources / National Register nomination  
  https://www.dhr.virginia.gov/VLR_to_transfer/PDFNoms/128-0352_Roanoke_Star_1999_Final_Nomination.pdf

---

## 3. Overall geometry: not a regular pentagram

A regular upright five-point star with height 88.5 ft would have width:

\[
W/H \approx 1.051462
\]

So:

\[
88.5 \times 1.051462 \approx 93.054 \text{ ft}
\]

But the Smithsonian survey gives:

\[
W/H = 84.5 / 88.5 \approx 0.954802
\]

That is radically different.

### Conclusion

The Roanoke Star is **vertically elongated relative to a mathematically regular pentagram**.

This means the following should **not** be assumed:

- 36° regular-pentagram point angle
- golden-ratio inner radius
- regular five-fold rotational geometry
- equal radial scaling of all nested contours

The reproduction should instead use the actual photographed silhouette and documented envelope.

---

## 4. Three structural frames vs. visible illuminated loops

### Current City description

The City of Roanoke describes the installation as **three stars / three frames**:

- outer
- middle
- inner

Each frame contains multiple clear neon tube sets.

The City has described each frame as containing roughly **3–5 sets of clear neon tubes**.

Source:

- City of Roanoke, Roanoke Star  
  https://www.roanokeva.gov/1329/Roanoke-Star

### What the all-white photos show

The strongest all-white frontal photographs clearly show **six dominant bright star contours**.

The most useful interpretation is:

- **Outer structural frame:** 2 closely paired visible tube tracks
- **Middle structural frame:** 2 closely paired visible tube tracks
- **Inner structural frame:** 2 closely paired visible tube tracks

Therefore:

\[
3 \text{ structural bands} \times 2 \text{ visible bright tracks} = 6 \text{ visible loops}
\]

This is the correct working topology for the all-white reproduction.

### Important distinction

These six visible loops are **not the same thing as six continuous physical neon tubes**.

Each visible star track is made from many shorter fabricated glass tube segments, mounted in pieces around the star.

Also, the City's “3–5 sets per frame” language likely refers to fabricated tube sets / circuitry / grouped tube pieces, not only the six dominant front-view luminous contours.

---

## 5. White configuration vs. red/white/blue configuration

The all-white configuration is the best target for reproduction because it exposes the underlying geometry.

### All-white configuration

Observed:

- six visible luminous contours
- grouped as three pairs
- all six visible at once
- cleanest geometry reference

### RGB / patriotic configuration

Some historical and modern RGB photos appear to show only **five obvious illuminated outlines**.

One commonly described arrangement is approximately:

- 1 red outer outline
- 2 white middle outlines
- 2 blue inner outlines

This can produce a **1 + 2 + 2 = 5** visual count.

Possible reasons:

- one outer contour may not be energized in that configuration
- color grouping may visually merge nearby tube tracks
- exposure / glow may obscure one adjacent contour
- different circuits may energize different tube subsets

This is why RGB photographs should not be used as the primary tube-count reference.

### Reproduction choice

**Target the all-white configuration.**

---

## 6. Historical descriptions that conflict

Several historical descriptions count the Star differently.

### “Three stars”

Current City terminology: three structural frames.

### “Five concentric stars”

A 1999 WDBJ historical retrospective, drawing on older interviews, described the approved 1949 design as involving **five concentric stars**.

Source:

- WDBJ archival transcript via Virginia Tech  
  https://scholar.lib.vt.edu/VA-news/WDBJ-7/script_archives/99/1199/112899/112899.m.htm

### “Nine rows” of neon

Virginia Room postcard material refers to approximately **nine rows** of neon and ~2,000 ft of tubing.

This is not necessarily contradictory if:

- “star” means a visible luminous outline
- “frame” means a structural carrier
- “row” means a tube row mounted on a frame
- “tube set” means a fabricated/electrical grouping

These terms appear to have been used inconsistently over time.

---

## 7. Fabrication history

A very useful historical account says the Star was assembled **flat on the ground at the Roanoke airport**, in front of an unused hangar.

The steel was:

1. laid out full scale
2. punched / fabricated
3. assembled for fit
4. disassembled
5. transported up Mill Mountain
6. reassembled on the tower

This matters because it strongly implies the original builders had either:

- dimensioned shop drawings
- full-scale lofting geometry
- templates
- or all of the above

The exact original blueprint has not yet been found online.

Source:

- WDBJ historical transcript  
  https://scholar.lib.vt.edu/VA-news/WDBJ-7/script_archives/99/1199/112899/112899.m.htm

---

## 8. Designer / contractor identities

### Star / sign contractor

**Roy C. Kinsey Sign Company**

Associated with design, fabrication, installation, lighting, panel work, and related sign construction.

### Structural support designer

Sources disagree slightly on the engineer's middle initial:

- **Robert R. Little**
- **Robert L. Little**

Associated with:

**Roanoke Iron & Bridge Works**

Both name variants should be searched in archival research.

### Neon tubing

Secondary historical material identifies **Corning Glass Works** as a tubing manufacturer associated with the installation.

---

## 9. DHR archival leads

The National Register file identifies:

- Resource: **128-0352**
- Photographer: **Anne Stuart Beckett**
- Date: **July 6, 1999**
- Negative: **17627**

Referenced views include:

1. north elevation
2. south and west elevations
3. north elevation
4. north elevation

These high-resolution elevation photographs could be extremely useful for perspective-corrected photogrammetry.

The nomination also credits:

- **Ken Harris**
- **Bill Liles**

of the Roanoke City Engineering Department.

This suggests City Engineering records were actively consulted during the 1999 documentation process.

---

## 10. Smithsonian archival lead

The Smithsonian's public SIRIS entry says an image is on file for inventory **IAS VA000441**.

The most useful archival request would ask for the complete field-survey packet, including:

- original measurement worksheet
- photographs
- sketches
- field notes
- dimensioning notes
- any attached drawings

The Smithsonian survey is currently the best source for the **84 ft 6 in width** measurement.

---

## 11. City engineering / modern structural-study lead

Later reporting documents:

- a **2019 structural inspection**
- a **2021 internal study**
- 2023 public discussion of restoration vs. replacement

Those studies reportedly identified issues involving:

- corrosion
- sheet-metal anchors
- coatings
- maintenance difficulty
- lead paint
- rehabilitation cost

The actual engineering report and attachments have not yet been located online.

These records may contain:

- modern measured elevations
- member-by-member dimensions
- annotated structural photos
- CAD/as-built drawings
- anchor details
- restoration measurements

This remains one of the strongest avenues for an exact reconstruction.

---

## 12. Unrelated archival drawing that was rejected

The Virginia Room contains 1941 drawings titled roughly:

**“Observation Tower for Roanoke, Virginia”**

These include:

- columns
- braces
- beams
- struts
- platforms
- anchor-bolt details
- erection diagrams

They initially looked promising, but they predate the 1949 Roanoke Star and refer to a different project.

**Do not use those dimensions for the Star.**

Their value is only that they prove the Virginia Room preserves large-format Roanoke structural drawings from the same era.

---

## 13. Photo-derived structural-frame proportions

From multiple front and near-front photographs, especially the all-white image and RGB references, the three major structural star frames appear roughly to scale as:

| Structural frame | Approx. relative scale |
|---|---:|
| Outer | **1.00** |
| Middle | **~0.74** |
| Inner | **~0.43** |

Using the documented outer envelope as a rough calibration gives:

| Frame | Approx. height | Approx. width | Confidence |
|---|---:|---:|---|
| Outer | **88.5 ft** | **84.5 ft** | documented envelope |
| Middle | **~65.4 ft** | **~62.5 ft** | photo-derived |
| Inner | **~38.2 ft** | **~36.4 ft** | photo-derived |

These internal dimensions are **not archival measurements**. They are working estimates from photographs.

Use them only as a starting point.

---

## 14. Photo-derived tube spacing

Measurements from the user-provided all-white frontal image showed six bright centerlines grouped into three pairs.

On one useful cross-section, approximate pixel positions were:

- Outer pair: ~155, 168
- Middle pair: ~195, 212
- Inner pair: ~240, 256

Approximate pair spacings:

- 13 px
- 17 px
- 16 px

Average:

\[
\approx 15.3 \text{ px}
\]

Approximate inter-band gaps:

- ~27 px
- ~28 px

Average:

\[
\approx 27.5 \text{ px}
\]

So:

\[
\frac{\text{inter-band gap}}{\text{in-band spacing}} \approx 1.8
\]

### Working spacing rule

> **The clear gap between structural star bands is roughly 1.8× the spacing between the paired luminous tracks on one band.**

This ratio is useful visually even if the absolute dimensions remain uncertain.

A rough real-world calibration suggested:

- tube-to-tube center spacing within one band: ~1.6–1.8 ft
- clear spacing from one band pair to the next: ~3 ft

These are very approximate and should not be treated as construction dimensions.

---
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

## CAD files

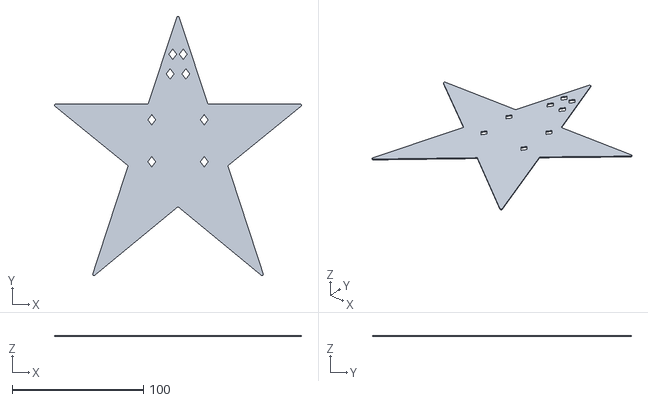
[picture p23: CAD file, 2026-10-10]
pentagrammic_prism/construction/inner_reflector.stl
188.6 x 197.6 x 0.8

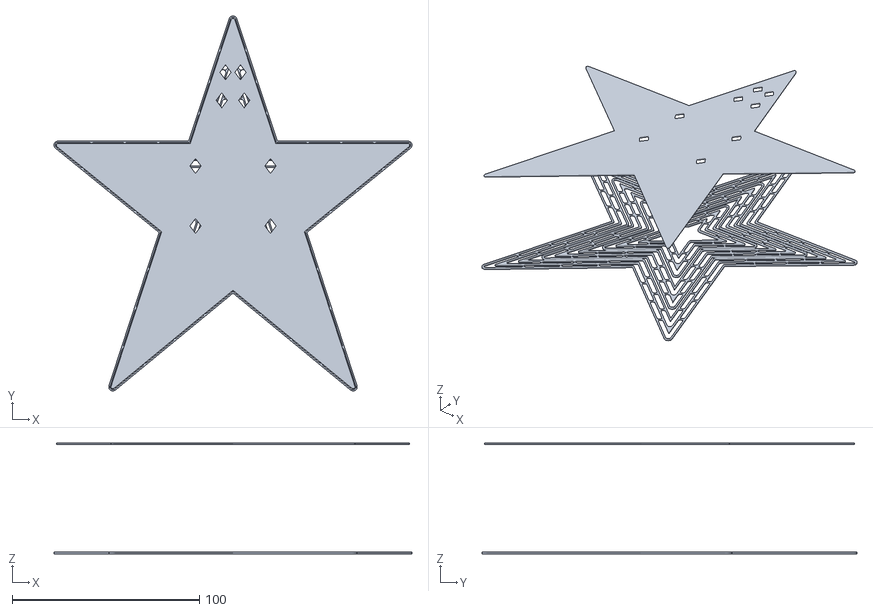
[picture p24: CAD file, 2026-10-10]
pentagrammic_prism/white_details.stl
191.0 x 200.0 x 59.2

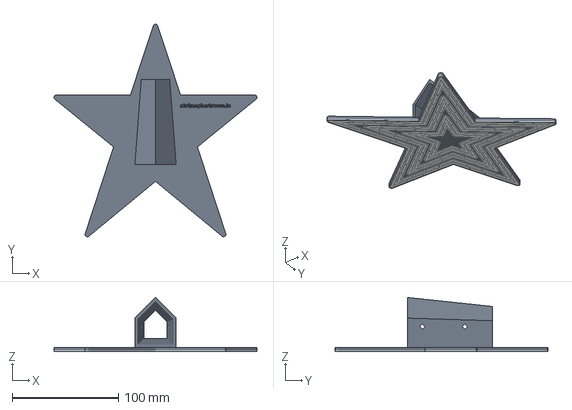
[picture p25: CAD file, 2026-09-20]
print_in_place/roanoke_star_A1.3mf
191.0 x 200.0 x 50.8 mm

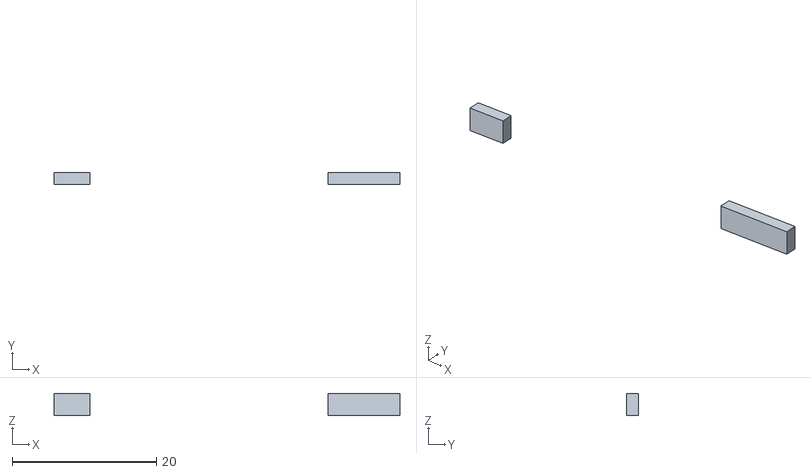
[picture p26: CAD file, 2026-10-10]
snap_back_prism/connector_fit_v2/construction/one_dot_rim.stl
48.0 x 1.60 x 3.10

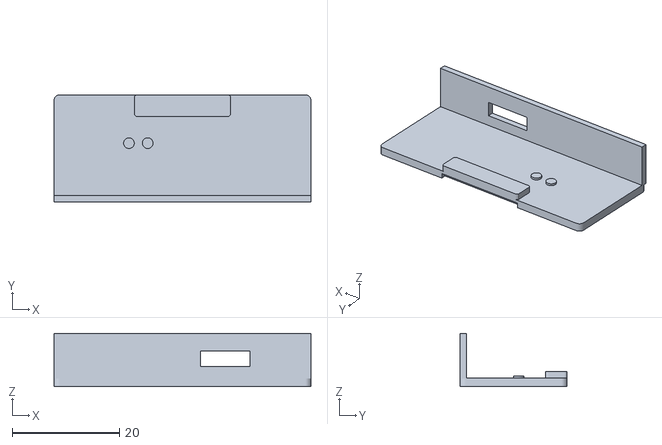
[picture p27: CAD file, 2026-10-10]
snap_back_prism/connector_fit_v2/two_dot_catch.stl
48.0 x 20.0 x 9.90

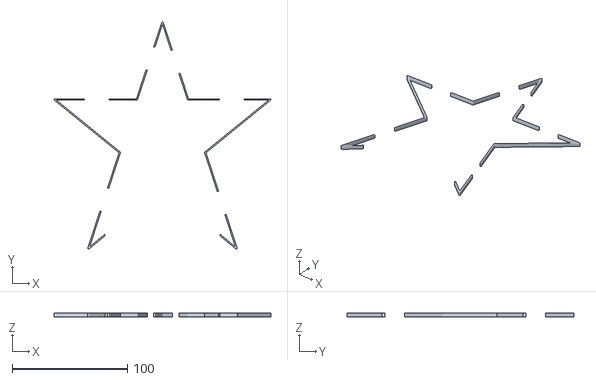
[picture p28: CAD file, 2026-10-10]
snap_back_prism/construction/locating_rim.stl
188.0 x 197.0 x 3.10

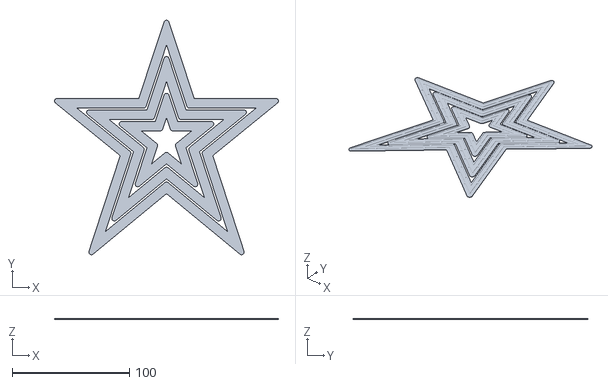
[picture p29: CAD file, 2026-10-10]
snap_back_prism/diffused/body_white_diffused.stl
191.0 x 200.0 x 1.00

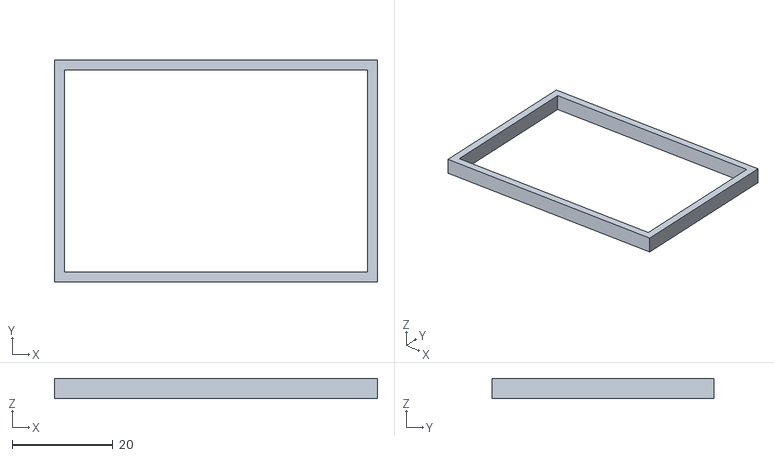
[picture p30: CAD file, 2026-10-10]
snap_back_prism/diffused/construction/sample_handling_border.stl
64.0 x 44.0 x 4.00

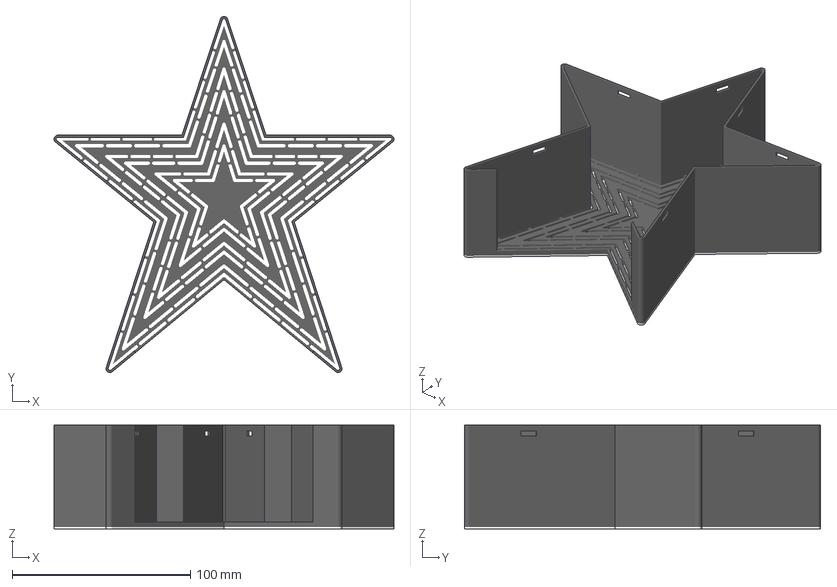
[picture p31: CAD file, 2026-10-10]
snap_back_prism/proportions_v2/front_shell_A1.3mf
191.0 x 200.0 x 58.4 mm

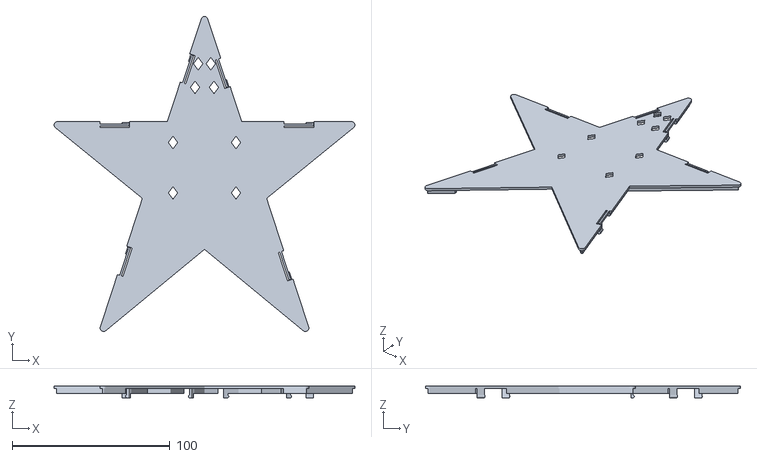
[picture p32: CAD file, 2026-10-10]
snap_back_prism/snap_back.stl
191.0 x 200.0 x 7.60

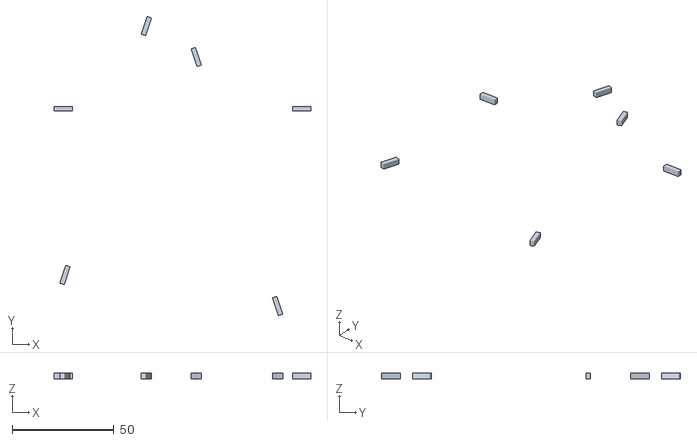
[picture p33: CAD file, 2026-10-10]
snap_back_prism/two_dot/construction/catch_windows.stl
126.1 x 146.9 x 2.90

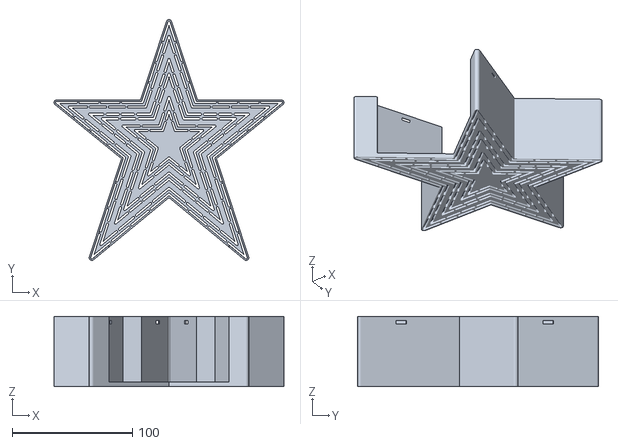
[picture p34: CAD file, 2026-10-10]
snap_back_prism/two_dot/front_shell_fused.stl
191.0 x 200.0 x 58.4

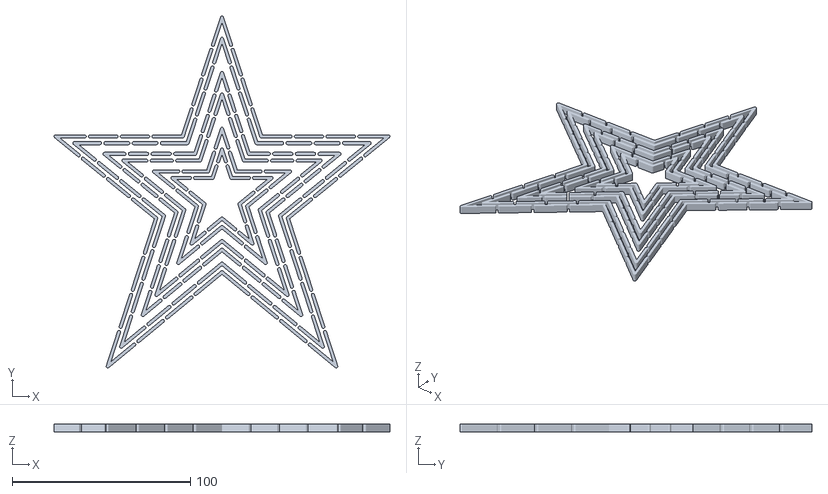
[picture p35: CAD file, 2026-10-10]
pentagrammic_prism/construction/white_tube_sections.stl
188.4 x 197.4 x 4.40

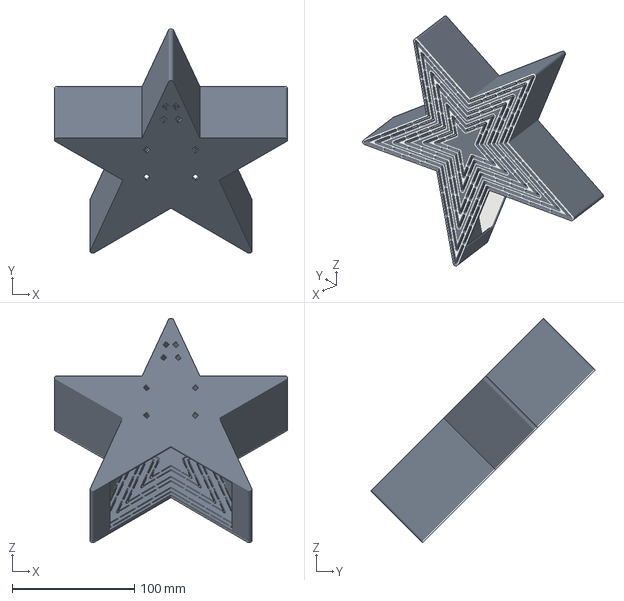
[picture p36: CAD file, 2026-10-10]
pentagrammic_prism/roanoke_star_prism_A1.3mf
191.0 x 183.8 x 183.8 mm

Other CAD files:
snap_back_prism/spacing_v3/front_shell_A1.3mf
print_in_place/body_material.stl
snap_back_prism/connector_fit_v2/construction/two_dot_wall.stl
snap_back_prism/connector_fit_v2/two_dot_back.stl
pentagrammic_prism/construction/bottom_mouth.stl
pentagrammic_prism/construction/canonical_white_face.stl
pentagrammic_prism/construction/canonical_white_reflector.stl
pentagrammic_prism/construction/inner_cavity.stl
pentagrammic_prism/construction/outline.stl
pentagrammic_prism/construction/rear_vents.stl
pentagrammic_prism/construction/tree_leader_clearance_reference.stl
pentagrammic_prism/construction/white_backing_bands.stl
pentagrammic_prism/dark_shell.stl
pentagrammic_prism/roanoke_star_prism.blend
pentagrammic_prism/roanoke_star_prism.stl
pentagrammic_prism/roanoke_star_prism_A1_single_color.3mf
print_in_place/roanoke_star_A1.blend
print_in_place/roanoke_star_A1_geometry_reference.stl
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

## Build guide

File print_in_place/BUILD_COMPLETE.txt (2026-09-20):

A1 model built and finalized through Blender GUI. Scene/STL equality, material geometry, lettering, package round trip, and native Bambu Studio two-color slicing checks passed. The backing-band and engraving revision has not been physically printed. See RELEASE_STATUS.json and slicer_validation.json.

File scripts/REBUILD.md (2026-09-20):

# Rebuilding and validating the A1 model

The current deliverables are in `print_in_place/`. The A1 rebuild uses included numerical profiles and does not require reference photographs. It uses two material regions in one fused print, an integral mount, three white backing bands, and recessed rear attribution. The shell scripts require Python with NumPy, Shapely, Trimesh, Manifold3D, and mapbox-earcut. The Blender build uses a locally installed Arial Bold TTF for the lettering; the font file is not distributed.

Use Python 3 with numpy, scipy, Pillow, shapely, trimesh, mapbox-earcut, and manifold3d installed. The GUI build was performed in Blender 5.2.1 LTS. The new scripts resolve the repository location from `__file__`.

1. Run `python3 scripts/prepare_a1_print_in_place.py`. This reads the six candidate paths from `research/photographic_paths.json`, fits exact parallel inward offsets, generates the rounded outline and 130 segmented inlay profiles, and records dimensions and the section schedule. The source record contains only the measured path coordinates and their provenance.
2. Open Blender's Python console and execute the build using the actual checkout path. The build replaces the scene's objects, so use the project scene rather than an unrelated unsaved file.

   ```python
   __file__ = '/absolute/path/to/roanoke-star-tree-topper/scripts/build_a1_print_in_place_blender.py'
   exec(compile(open(__file__).read(), __file__, 'exec'))
   ```

3. Run `python3 scripts/canonicalize_a1_body.py` in the shell to repair coplanar triangulation in both materials. Then execute `scripts/apply_a1_canonical_body_blender.py` in the same Blender GUI console using the `__file__` pattern. It returns both repaired meshes to Blender and re-exports them. Finally execute `scripts/check_a1_blender.py` there; it checks both actual color meshes for non-adjacent triangle intersections without adding an exclusion tolerance.
4. Run `python3 scripts/validate_package_a1.py` in the shell. It validates material coverage, the engraved lettering, overhangs, mandrel clearance, and 3MF round-trip geometry. It packages Bambu part-to-filament assignments and the A1 preset snapshot in `a1_bambu_settings.json`. The snapshot uses Bambu Studio 02.05.00.66's built-in A1 and Generic PLA presets with this project's documented process settings. Inspect the reports; successful execution is required.
5. Render the previews in the same Blender console:

   ```python
   render_view('front.png', (0, 0, -440), (0, 0, 0), 234)
   render_view('three_quarter.png', (245, 100, -360), (0, 0, 12), 248)
   render_view('rear.png', (150, 75, 390), (0, 0, 18), 248)
   render_view('rear_detail.png', (47, 23, 220), (47, 23, 3.7), 62)
   render_view('side.png', (440, 0, 22), (0, 0, 22), 234)
   ```

6. Inspect all five images. Open the generated 3MF as a project in Bambu Studio and confirm filament 1 on the dark body and filament 2 on the white face. Confirm that the process retains four walls, five top and bottom layers, 15% gyroid infill, Arachne, and supports disabled. Slice and inspect the first five layers, both lower interior corners, the transition to the dark body, and the socket roof. Export G-code locally through File → Export → Export G-code; no printer connection or print command is needed. Run `python3 scripts/check_a1_sliced_gcode.py /path/to/export.gcode --output /path/to/checks.json` to check actual process values and model extrusion by color and height. Record the inspected package's SHA-256 and the separate visual observations in `print_in_place/slicer_validation.json`; the G-code audit alone does not establish which file was opened or whether the layers were visually inspected. Run `validate_package_a1.py` again to associate that evidence with the exact package. Update `print_in_place/RELEASE_STATUS.json` to match the evidence. Execute `scripts/finalize_a1_blender.py` in the GUI console using the same `__file__` pattern. It checks that scene exports match the validated STLs, embeds current reports, license, and scripts, and saves an upright front view.
7. Run `python3 scripts/sanitize_release_metadata.py` before sharing the files. It removes textual metadata from the rendered PNGs without changing their image data and replaces local home paths in the Blender file with same-length placeholders. Compressed Blender files require the `zstd` command. The script also checks the 3MF for local paths and account metadata.

The geometry-reference STL is the complete outer solid before color partitioning. A monochrome print loses the contrasting tube pattern. The two material STLs retain the identical origin and belong to one multipart object; do not auto-arrange or print them independently.

Mesh validity and landmark accuracy are separate criteria. Changes to inferred paths require additional evidence; see [the accuracy audit](../research/ACCURACY_AUDIT.md). The owner's successful print used the earlier tube-only face; the band-and-lettering revision still needs a physical print to evaluate its surface quality. Strength, branch fit, and retention are not established by geometry checks.

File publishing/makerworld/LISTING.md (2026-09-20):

# Roanoke Star Christmas Tree Topper — Two Colors, No Assembly

Bring a little of Roanoke's Mill Mountain to your Christmas tree. This 200 mm topper captures the landmark's layered neon appearance with **130 individual tube sections, three white star bands, and crisp dark outlines**. The star and its rear tree socket print together as one piece.

The white tubes and backing bands are flush inlays. Thin dark outlines keep each tube distinct, including the bends around the points and lower recesses. The back has recessed **christopherbrown.io** lettering.

## Print setup

- **Printer:** Bambu Lab A1 with AMS lite
- **Nozzle / layers:** 0.4 mm / 0.20 mm
- **Filaments:** two compatible PLA colors — black or navy for the body and outlines, white for the face details
- **Size:** 200 mm tall × 190.96 mm wide × 50.84 mm deep
- **Orientation:** decorated face against the build plate
- **Process:** four walls, five top and bottom layers, 15% gyroid infill, Arachne walls, prime tower enabled, supports disabled
- **Assembly:** none

Open the 3MF **as a project** in Bambu Studio and map filament 1 to your dark spool and filament 2 to white. The decorated face occupies the **first five layers**; view those layers in the sliced preview to see both colors. The full-height view looks mostly dark because the white face is against the bed. The included plate setting is Textured PEI; select the plate you actually use.

The A1 slice estimates **2 h 47 min and 70.5 g of PLA**, including purge and prime-tower material. Estimates vary with filament profiles and settings.

The integrated socket is 80 mm long with nominal circular clearance tapering from Ø34 to Ø22 mm. Rear diamond-shaped holes accept optional retaining ties. Check your tree leader against these dimensions before printing.

For the alternative STL download, import **both material files together as parts of one object**, preserve their shared position, and assign the two colors. The separate meshes form one finished print.

## A Christmas landmark since 1949

The Roanoke Merchants Association commissioned the Mill Mountain Star for the 1949 Christmas season. First illuminated on November 23, 1949, the 88.5-foot landmark became a permanent part of the city's skyline.

This model grew out of municipal and historical records, an original-plan search, and comparisons of more than fifteen photographs and views. The research considered the perspective distortion in photographs taken from below and used parallel offsets to keep the nested tube paths consistent. It is a photographic interpretation of the landmark; no original dimensioned shop drawing was located in the sources reviewed. The 130 tube sections describe this model's pattern.

The gallery includes photographs of the owner's completed two-color print with the three white backing bands. The festive cover is an **AI-generated product illustration** based on the model and print photographs; use the actual print photos to judge the surface finish. The included A1 project has also been opened, sliced, and inspected in Bambu Studio 02.05.00.66.

Model, editable Blender source, and detailed research: [GitHub project](https://github.com/christopherrbrown3/roanoke-star-tree-topper).

## License and credit

**CC BY-NC-SA 4.0** — share and adapt for noncommercial use with attribution, and share adaptations under the same license.

Roanoke Star Tree Topper by **christopherrbrown3** · **christopherbrown.io**.

Historical source: [City of Roanoke — Roanoke Star](https://www.roanokeva.gov/1329/Roanoke-Star).

## Print-profile copy

**Title:** A1 · 0.20 mm · Two-color PLA · No supports

**Description:** One face-down object, two PLA filaments, and an integrated tree socket. A1 with AMS lite and a 0.4 mm nozzle. Four walls, five top/bottom layers, 15% gyroid, Arachne walls, and a prime tower. Assign dark PLA to filament 1 and white PLA to filament 2. Both colors appear in layers 1–5; the remaining body and socket use the dark filament. Approximately 2 h 47 min and 70.5 g including purge and tower material. No assembly or supports.

## Discovery tags

roanoke star, mill mountain star, christmas tree topper, tree topper, christmas, virginia, two color, print in place, bambu a1, ams lite

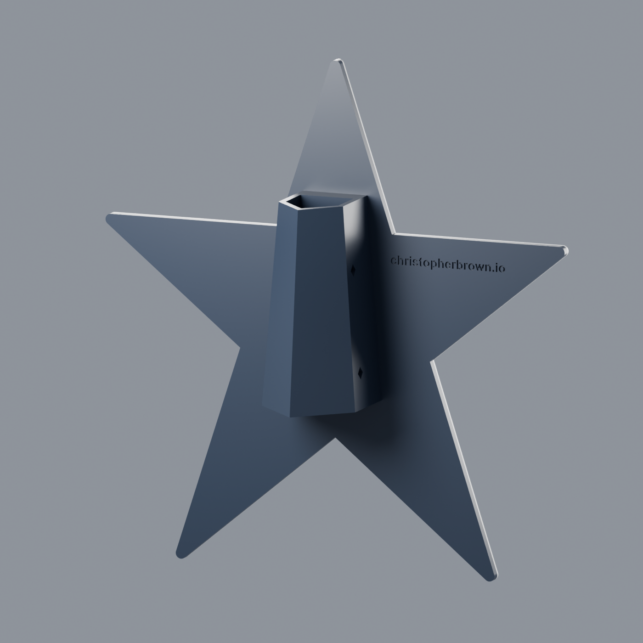
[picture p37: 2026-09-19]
print_in_place/previews/rear.png

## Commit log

2026-09-10 Preserve Roanoke Star design candidates and document accuracy audit
    [Roanoke_Star_Tree_Topper.blend, Roanoke_Star_Tree_Topper_180mm.stl, mill_mountain_star_topper_assembly.stl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]
2026-09-12 Repair light meshes and preserve research for individual tube revision
    [candidate_angles.csv, roanoke_star_assembled.stl, roanoke_star_lights.stl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]
2026-09-13 Add single-print A1 model and prepare parallel tube correction
    [body_material.stl, candidate_angles.csv, roanoke_star_A1.3mf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]
2026-09-13 Rebuild parallel tube geometry and validate A1 exports
    [body_material.stl, roanoke_star_A1.3mf, roanoke_star_A1.blend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]
2026-09-13 Keep main focused on the current A1 model and research
    [Roanoke_Star_Tree_Topper.blend, Roanoke_Star_Tree_Topper_180mm.stl, mill_mountain_star_topper_assembly.stl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]
2026-09-19 Add white backing bands, rear attribution, and model license
    Preserve the parallel tube paths, add three white backing bands with dark tube outlines, and recess christopherbrown.io on the back.
    Include CC BY-NC-SA 4.0 licensing, explicit Bambu filament assignments, updated renders, and spacing research. Document the saved Blender construction checkpoint and incomplete native sliced-layer ch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
    [body_material.stl, roanoke_star_A1.3mf, roanoke_star_A1.blend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]
2026-09-20 Preserve A1 process overrides and verify native two-color slicing
    [roanoke_star_A1.3mf]
2026-09-20 Finalize Blender source and polished validated-release documentation
    [roanoke_star_A1.blend]
2026-09-20 Add MakerWorld publication assets and print evidence
2026-10-10 Add hollow snap-back Roanoke topper with diffused stars and corrected spacing (#4)
    * Add hollow pentagrammic prism tree topper variant
    * Experiment with face-down prism and snap-on back
    * Apply preferred two-dot connector to full snap-back topper
    * Add larger recessed builder mark to snap-back cover
    * Add two-layer white diffusers and face test print
    * Remove bulb outlines from the diffused star face
    * Refine diffuser star spacing in V3
    [back_unmarked_reference.stl, body_black.stl, body_blank.stl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]
2026-10-16 Add recovered prototype photos to MakerWorld draft
2026-10-16 Add complete two-plate snap-back project (#5)

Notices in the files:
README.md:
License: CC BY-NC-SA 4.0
